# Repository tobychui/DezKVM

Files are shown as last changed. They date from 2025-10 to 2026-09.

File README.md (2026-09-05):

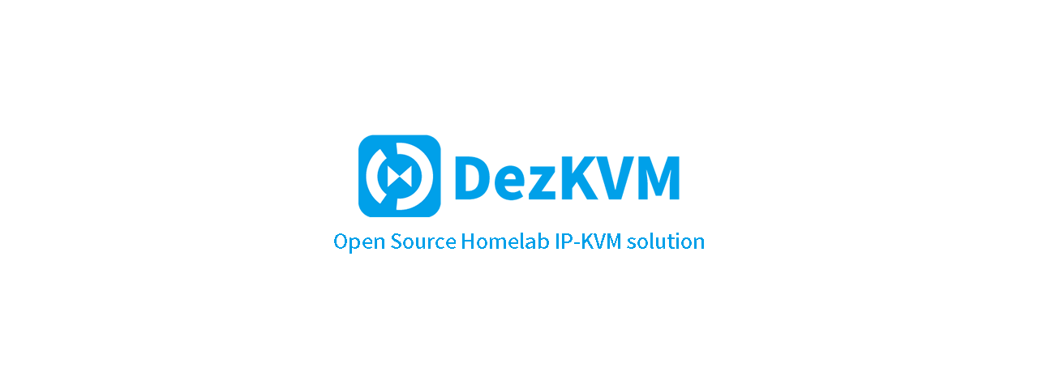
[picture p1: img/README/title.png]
title


# DezKVM — The DIY Multi-Port IP-KVM

DezKVM is an open-source, ultra-low-cost multi-port IP-KVM designed to run on standard Linux systems.

Instead of using HDMI to CSI adapter or proprietary capture hardware, DezKVM uses fully USB-based components supported by upstream Linux drivers (V4L2 and ALSA). This means the system runs on common embedded platforms such as SBCs and mini PCs without requiring any kernel patches or vendor drivers.

The goal of DezKVM is simple:

**Make scalable IP-KVM infrastructure affordable, hackable, and easy to build using commodity hardware.**

> [!WARNING]
> This project is in its very early stage and not production ready. Use with your own risk. 

If you are looking for a KVM over USB or USB-KVM device, visit [DezKVM Go](https://github.com/tobychui/DezKVM-Go) Project.

## Why DezKVM Exists

Existing DIY solutions significantly reduce cost compare to commercial solutions, but many still rely on custom kernels, specific SBC provided IO, or tightly coupled hardware platforms. 

**DezKVM takes a different approach.** 

Instead of reinventing drivers or hardware stacks, DezKVM builds entirely on top of standard USB devices already supported by Linux:

- USB Video - handled by upstream **V4L2**
- USB Audio - handled by **ALSA**
- USB HID - physical, off-the-shelf **UART to HID ASIC**
- USB ATX - communicate to host software using **USB CDC**
- All connected using a standard USB 2.0 hub

Because of this design philosophy:

- No custom kernel patches / proprietary drivers
- Works on most Linux SBCs and mini PCs (as host)
- High compatibility on different (remote) computers
- Easy multi-port scaling

## Comparison

| Feature | DezKVM | PiKVM | JetKVM | GL.iNet KVM |
| --- | --- | --- | --- | --- |
| Open Source | ✅ Fully | ✅ Mostly | ⚠️ Partial | ❌ No |
| DIY Friendly | ✅ Yes | ✅ Mostly (v1 & v2) | ❌ No | ❌ No |
| Multi-Port Support | ✅ Scale using USB hubs | ⚠️ Expensive KVM Switch required | ❌ Single Target | ❌ Single Target |
| Multi-View Support | ✅ Yes | ⚠️ Require switching | ❌ No | ❌ No |
| Hardware Lock-in | ❌ None | ⚠️ Raspberry Pi | ✅ Vendor HW | ✅ Vendor HW |
| Uses Standard Linux Drivers | ✅ Yes | ⚠️ Partial | ❌ Custom Stack  | ❌ Proprietary |
| Custom Kernel Required | ❌ No | ⚠️ Sometimes | ✅ Yes | ✅ Yes |
| Cost per Remote | ⭐ Very Low | Medium | High | High |
| Offline Operation | ✅ Yes | ✅ Yes | ✅ Yes | ✅ Yes |
| Hackable / Extendable | ✅ High | Medium | Low | Very Low |

## Build

### Dezkvmd (DezKVM daemon)

The Dezkvmd is a golang written piece of code that runs on a x86 or ARM computer with Debian based Linux installed. Require v4l2 and alsa with kernel 6.1 or above.  

To build the dezkvmd, you will need go compiler. The go package manager will take care of the dependencies during your first build. 

```bash
cd dezkvmd/
go mod tidy
go build

sudo ./dezkvmd
# or use ./dezkvmd -h to show all start options
```
### Setup Systemd Service

Create a systemd service file at `/etc/systemd/system/dezkvmd.service`:

```ini
[Unit]
Description=dezKVM IP-KVM Daemon
After=network-online.target
Wants=network-online.target

[Service]
Type=simple
User=root
WorkingDirectory=/path/to/DezKVM/src/dezkvmd
ExecStart=/path/to/DezKVM/src/dezkvmd/dezkvmd -mode=ipkvm
Restart=always
RestartSec=5

[Install]
WantedBy=multi-user.target
```

Replace `/path/to/dezKVM` with the actual path to your dezKVM installation directory.

Then enable and start the service:

```bash
sudo systemctl daemon-reload
sudo systemctl enable dezkvmd
sudo systemctl start dezkvmd
```

Check the service status:

```bash
sudo systemctl status dezkvmd
```

#### Install Dependencies

Some packages are required to run DezKVM (Require Linux kernel 6.1 or above, Debian based distro recommended). If your `go build` command above failed due to missing v4l2 types or user space properties, you can install the dependencies by running the following command. 

```
sudo apt install build-essential libv4l-dev v4l-utils 
```

If your system fail to capture audio output from remote device, or show invalid audio device properties, install the missing alsa utilities with the following command. 

```
sudo apt install alsa-utils
```

Disk formatting also requires some of the packages to provide support for file system types like exFAT or NTFS if they are not already avaible on your system. 

```
sudo apt install exfatprogs ntfs-3g
```

### Hardware

#### Build your own hardware

See `hardware/README.md`

## Usage

### Video Capture Configs

By default, MS2109 HDMI capture card support the following resolutions. If you are connecting to your DezKVM via the internet (not recommended), pick a resolution and fps combination that best fit your network **upload** bandwidth. If you are using your DezKVM within your internal management network, you can just pick the FHD 25 / 30fps option since local area network are at least 100mbps at the time of writing.

```
// FHD
1920 x 1080 30fps = 50Mbps
1920 x 1080 25fps = 40Mbps
1920 x 1080 20fps = 30Mbps
1920 x 1080 10fps = 15Mbps

// HD
1360 x 768 60fps = 28Mbps
1360 x 768 30fps = 25Mbps
1360 x 768 25fps = 20Mbps
1360 x 768 20fps = 18Mbps
1360 x 768 10fps = 10Mbps
```

### USBKVM-App

The USBKVM-App is a debug tool for the USB-KVM section of the DezKVM build that also serve as a USB-KVM viewer. It is used for checking if the USB-KVM subsystem works before integrating into a larger IP-KVM system. See `tools/usbkvm-app/` for more information.

## Screenshots

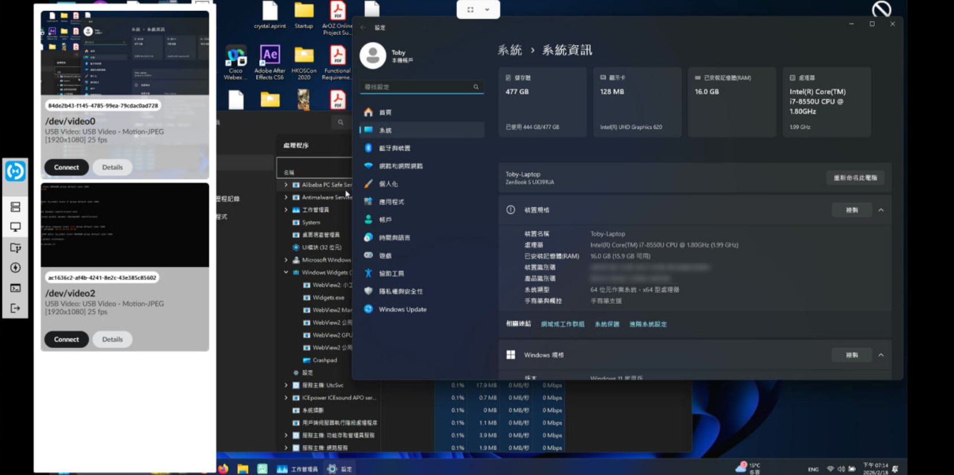
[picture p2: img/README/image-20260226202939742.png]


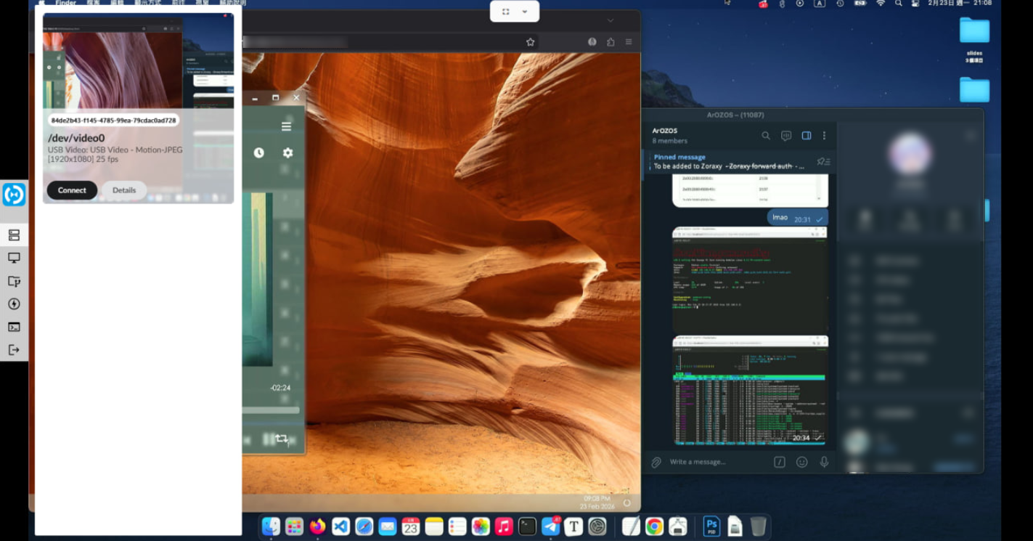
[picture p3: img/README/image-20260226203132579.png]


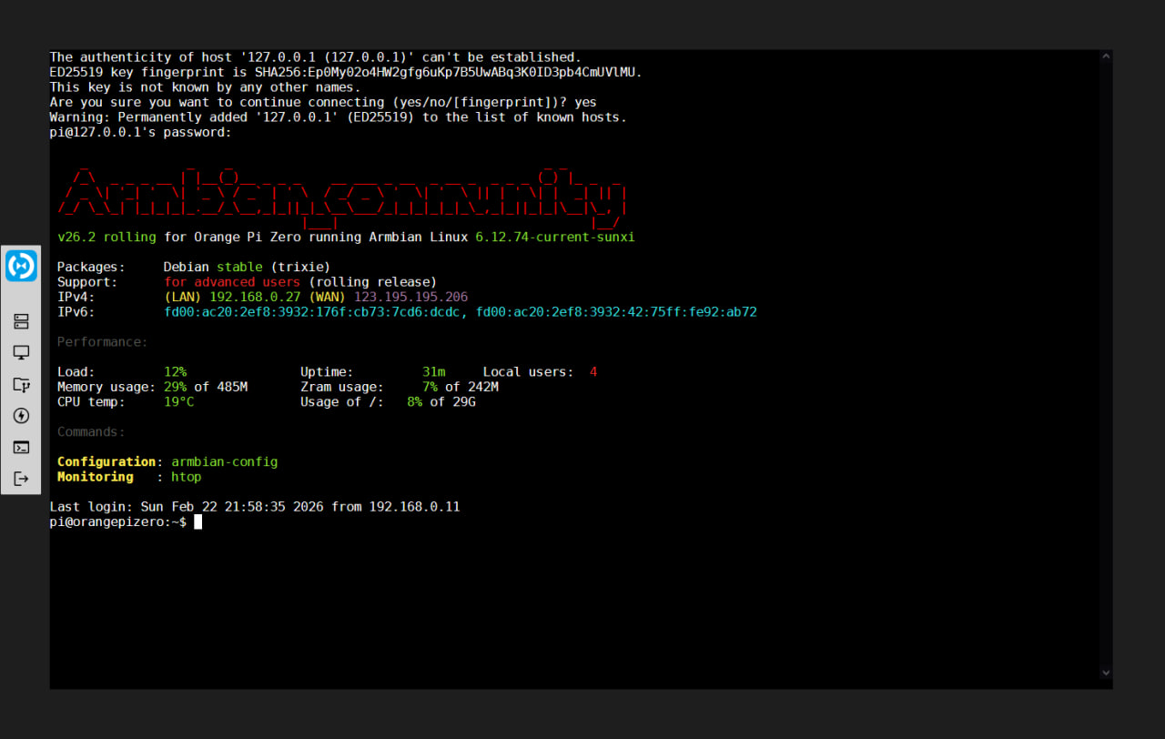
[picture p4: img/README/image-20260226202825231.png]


## License

DezKVM
Copyright (C) 2025 Toby Chui

DezKVM is free software; You can redistribute it and/or modify it under the terms of:
  - the GNU Affero General Public License version 3 as published by the Free Software Foundation.
You don't have to do anything special to accept the license and you don’t have to notify anyone which that you have made that decision.

DezKVM is distributed in the hope that it will be useful, but WITHOUT ANY WARRANTY;
without even the implied warranty of MERCHANTABILITY or FITNESS FOR A PARTICULAR PURPOSE.
See your chosen license for more details.

You should have received a copy of both licenses along with DezKVM.
If not, see <http://www.gnu.org/licenses/>.

**Note: There will be no support if you are using 3rd party parts or systems. If you are creating a new issue, make sure you are using the official implementation here with the recommended hardware and software setups**

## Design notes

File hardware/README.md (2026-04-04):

# Hardware Guide

This guide walks you through building, flashing, and cabling the DezKVM IP-KVM system from scratch. It is written with first-time hardware builders in mind — do not skip sections, as each step builds on the previous one.

---

## Table of Contents

1. [System Overview](#system-overview)
2. [Components](#components)
3. [Building the DezKVM PoC USB-KVM Module](#building-the-dezkvm-poc-usb-kvm-module)
4. [Flashing the Onboard CH552G MCU](#flashing-the-onboard-ch552g-mcu)
5. [Configuring the CH9329 Baud Rate](#configuring-the-ch9329-baud-rate)
6. [Connecting to a Host SBC (Multiple KVM Ports, No HDMI Switch)](#connecting-to-a-host-sbc-multiple-kvm-ports-no-hdmi-switch)
7. [Building and Connecting the ATX Board](#building-and-connecting-the-atx-board)
8. [Optional: OLED HMI Display](#optional-oled-hmi-display)
9. [Troubleshooting](#troubleshooting)

---

## System Overview

DezKVM is a fully **USB-protocol-based** IP-KVM system. Unlike PiKVM and similar projects, it does not require a dedicated HDMI switch, HDMI-to-CSI adapter, custom kernel drivers, or an FPGA. Everything on the DezKVM port module enumerates as standard USB devices — the host SBC sees a USB hub containing a video capture device, a USB-to-UART adapter, and a serial ACM device. This means the Linux kernel requires no patches or custom modules.

A complete system looks like this:

```
[ Host SBC (Orange Pi / Raspberry Pi / etc.) ]
         |
    USB 2.0 cable (one per KVM port)
         |
[ DezKVM Port Module ] ── HDMI ──► [ Remote Computer being controlled ]
         |                ─── USB-C (HID) ──────────────────────────►
         |                ─── RJ45 ATX cable ──► [ ATX Board ]
         |                                               |
         |                                   Dupont wires to front-panel header
```

You can connect **multiple DezKVM Port Modules** to a single host SBC — one per computer you want to control. The `dezkvmd` daemon on the SBC identifies each module by its unique UUID and routes keyboard/mouse/video to the correct session. There is no need for any external HDMI matrix switch or KVM switch box.

---

## Components

Before you start building, gather everything listed below.

### Per DezKVM Port Module

| Item | Notes |
|---|---|
| DezKVM PoC PCB (v8 recommended) | Order from your PCB fab using the Gerber files in `DezKVM PoC/pcb/v8/` |
| MS2109 HDMI capture card module | A small plug-in module; search for "MS2109 HDMI capture card" — they are very inexpensive |
| All SMD components per BOM | BOM CSV is provided in `DezKVM PoC/pcb/v8/` |
| 3D-printed enclosure | STL files in `DezKVM PoC/3d_models/` (front, back panels + HDMI capture holder) |

### For ATX Power Control (optional, one per controlled computer)

| Item | Notes |
|---|---|
| ATX Board PCB | Gerber files in `ATX board/PCB/` |
| RJ45 connector (18.3 mm pitch) | Connects the ATX board to the Port Module |
| 4× 2×2p 2.54 mm male pin headers | Front-panel connector blocks |
| 5× M3×5 mm screws | For mounting |
| Dupont wires | 8× Male-to-Female (front-panel to ATX board) + 8× Female-to-Female (ATX board to motherboard header) |
| 3D-printed parts | `ATX board/3d_models/` — PCIe bracket, mount, and optional cable press |

### Host SBC

Any Linux-capable single-board computer with USB 2.0 ports works. More USB ports means more KVM ports you can run simultaneously:

| SBC | Ethernet | USB Ports | Recommended Port Modules | Max Concurrent Sessions |
|-----|---|---|---|---|
| Orange Pi Zero LTS | 100 Mbps | 3 | 1–2 | 1 |
| Orange Pi Zero 2 | 1 Gbps | 3 | 2–4 | 4 |
| NanoPi Zero 2 | 1 Gbps | 1 | 1–4 | 4 |
| Raspberry Pi 4 | 1 Gbps | 4 | 4 | 4 |

> You can always add more Port Modules. The limits above are practical bandwidth guidelines — each module uses ~80–90 Mbps at 1080p 25 fps MJPEG.

---

## Building the DezKVM PoC USB-KVM Module

### Step 1 — Order the PCB

Open `DezKVM PoC/pcb/v8/` and upload the Gerber zip file to a PCB fabrication service (JLCPCB, PCBWay, etc.). Standard 2-layer, 1.6 mm FR4 settings work fine. If the fab offers SMT assembly, the BOM CSV and Pick & Place CSV are also provided in that folder for JLCPCB assembly service.

### Step 2 — Solder the components

If you are assembling by hand, use the schematic PDF in `DezKVM PoC/pcb/v8/` as your reference. Key chips and their placement:

| Chip | Role | Notes |
|---|---|---|
| SL2.1A | USB 2.0 hub | Groups all downstream devices under one USB tree |
| CH552G | Onboard MCU | Handles ATX control, USB mass-storage switching, UUID service, HDMI power control |
| CH340C | USB-to-UART bridge | Bridges the SBC's USB to the CH9329 |
| CH9329 | UART-to-USB-HID | Emulates keyboard and mouse on the remote side — no driver needed on the controlled PC |
| CH440G | USB signal switch | Routes the internal USB Type-C port between SBC and remote |
| MS2109 module | HDMI capture | Plug-in module; press it into the slot on the PCB |

> **First-time soldering tip:** Start with the smallest SMD components first (resistors and capacitors), then the ICs, and finish with connectors. For the QFN/SOP packages, use plenty of flux and a fine-tipped iron. Review the PCB silkscreen for all component orientations before powering on.

### Step 3 — Print and assemble the enclosure

Print the STL files from `DezKVM PoC/3d_models/`. The assembly consists of:
- **front.ipt / front.stl** — front plate with HDMI and USB-C cutouts
- **back.ipt / back.stl** — back plate with host-side USB-C and PROG header access
- **capture_holder_top / capture_holder_bottom** — holds the MS2109 module in the correct position

PLA at 0.2 mm layer height works well. Orient the flat face of each part down when printing to avoid supports.

### Step 4 — Ports at a glance

Once assembled, you will see:

**Remote side (faces the computer you are controlling):**
- HDMI input — connect to the remote computer's HDMI output
- RJ45 ATX control port — connect to the ATX board (optional)
- USB-C (upper) — USB mass-storage passthrough
- USB-C (lower, closer to HDMI) — USB HID (keyboard + mouse to remote PC)

**Host side (faces your SBC):**
- USB-C (USB 2.0) — single cable to your SBC; everything goes through this
- XH2.54 1×4p white header — alternative connection if you prefer a JST header over USB-C
- PROG header (unpopulated by default) — only needed for certain reprogramming scenarios

---

## Flashing the Onboard CH552G MCU

The CH552G is an 8051-based microcontroller that runs the ATX control, UUID service, and HDMI power management firmware. It is programmed using the Arduino IDE with the **ch55xduino** board support package.

### Prerequisites

1. Download and install [Arduino IDE](https://www.arduino.cc/en/software) (version 2.x recommended).
2. In Arduino IDE, go to **File → Preferences** and add this URL to the "Additional boards manager URLs" field:
   ```
   https://raw.githubusercontent.com/DeqingSun/ch55xduino/unreal/package_ch55xduino_mcs51_index.json
   ```
3. Open **Tools → Board → Boards Manager**, search for `CH55x`, and install the ch55xduino package.
4. Open the firmware sketch that matches your PCB version from `DezKVM PoC/firmware/`. For v7 or v8 PCBs, use `For v7 PCB/usbkvm_fw/usbkvm_fw.ino`.

### First-Time Flash (bootloader mode entry)

The CH552G ships without firmware. To enter its USB bootloader, you must hold down the FLASH button on the PCB **before** the chip sees USB power. Follow these steps exactly in order:

1. Open the firmware sketch in Arduino IDE and click **Compile** (the tick/check button). Wait for it to finish — this caches the binary and makes the next step faster.
2. Set the upload settings under **Tools**:
   - **Clock**: `24MHz (Internal)`
   - **Upload method**: `USB CODE w/ 148B USB RAM`
3. **Hold down the FLASH button** on the PCB. Do not release it yet.
4. While still holding FLASH, plug the **host-side USB-C cable** from the PCB into your PC.
5. Check your device manager (Windows) or `lsusb` (Linux). You should see:
   - A USB hub (SL2.1A)
   - A USB video/audio device (MS2109 capture card, if installed)
   - A USB-to-UART adapter (CH340C)
   - An **Unknown Device** — this is the CH552G in bootloader mode
6. In Arduino IDE, click **Upload** (the right-arrow button). You do not need to select a serial port for the first flash.
7. Watch the IDE output. **The moment you see the compilation phase finish and the upload phase start, release the FLASH button.** This is the critical timing window:
   - Release too late → upload times out
   - Release too early → CH552G resets out of bootloader before the upload completes
   - If it fails, unplug the cable and repeat from step 3
8. When successful, the Unknown Device disappears from your device manager and a new **COM port / ttyACM device** appears. This is the CH552G running its firmware.

> The first flash is the hardest part of building this device. It may take 2–3 attempts to get the button timing right. This is normal — do not be discouraged.

### Subsequent Firmware Updates

After the first flash is done, the ch55xduino bootloader is triggered automatically via the serial port. Future updates work exactly like any Arduino board:

1. Select the correct COM port / ttyACM device under **Tools → Port**.
2. Click **Upload**.

No button holding is required.

---

## Configuring the CH9329 Baud Rate

The CH9329 (keyboard/mouse emulator chip) ships with a default baud rate of **9600 bps**, which is too slow for smooth KVM control. You need to change it to **115200 bps** once after first assembly.

> This step requires the `dezkvmd` software to be built. See the main `src/dezkvmd/` directory for build instructions.

1. Plug the **host-side USB-C** port into your SBC (or any Linux PC).
2. Take a separate USB power source (a phone charger is fine) and plug it into the **lower USB-C port** on the remote side of the KVM module — the one closer to the HDMI connector. This powers up the CH9329 independently so the configuration can reach it.
3. On the SBC / Linux machine, run:
   ```bash
   src/dezkvmd/configure_chip.sh
   ```
   If the CH340C UART adapter enumerated on a different path than `/dev/ttyUSB0`, edit `src/dezkvmd/config/usbkvm.json` to match before running the script.
4. Wait for the script to complete without errors.
5. Unplug the power from the lower USB-C port.
6. Connect the **remote computer's USB port** to that lower USB-C port — keyboard and mouse should now feel immediate and responsive.

---

## Connecting to a Host SBC (Multiple KVM Ports, No HDMI Switch)

This is the feature that sets DezKVM apart: **you do not need a dedicated HDMI switch** (like the PiKVM HDMI switch) because each port module is an independent USB device. Adding another KVM port just means plugging in another USB cable.

### How it works

Each DezKVM Port Module contains a **SL2.1A USB 2.0 hub** that groups all of its downstream USB devices under a single USB tree. When plugged into the SBC, the Linux kernel sees:

| Linux Device | What it is |
|---|---|
| USB hub (SL2.1A) | The "identity container" of one KVM port |
| `/dev/video*` + ALSA sound card | MS2109 HDMI capture — video and audio from the remote machine |
| `/dev/ttyUSB*` (ch341 driver) | CH340C UART bridge — the pipe that carries keyboard/mouse commands to CH9329 |
| `/dev/ttyACM*` (CDC ACM) | CH552G MCU — ATX control, USB mass-storage switching, UUID queries |

The `dezkvmd` daemon queries `u` (UUID command) on each `ttyACM` device at startup to build a map of **UUID → USB tree → video device + ttyUSB + ttyACM**. This is how it knows which keyboard/mouse pipe belongs to which video stream, even after rebooting or re-plugging modules.

### Single-port setup

```
[ SBC USB port 1 ]
      |
[ DezKVM Port Module 1 ]
      |── HDMI ──► Computer A
```

Connect the host-side USB-C of the Port Module to any USB 2.0 or USB 3.0 port on the SBC. USB 3.0 ports are backwards compatible with USB 2.0.

### Multi-port setup

```
[ SBC USB port 1 ] ──► [ DezKVM Port Module 1 ] ──► Computer A
[ SBC USB port 2 ] ──► [ DezKVM Port Module 2 ] ──► Computer B
[ SBC USB port 3 ] ──► [ DezKVM Port Module 3 ] ──► Computer C
```

Each module plugs directly into its own USB port on the SBC. If your SBC has fewer physical USB ports than you need, you can use a **USB 2.0 hub** to expand — just be aware that all modules behind the same hub share the bandwidth of that hub's upstream port.

```
[ SBC USB port 1 ] ──► [ USB 2.0 Hub ]
                               |──► [ DezKVM Port Module 1 ] ──► Computer A
                               |──► [ DezKVM Port Module 2 ] ──► Computer B
```

> **Bandwidth note:** Each module uses ~80–90 Mbps at 1080p 25 fps. USB 2.0 practical throughput is around 400 Mbps, so two modules per hub port is comfortable; four is the realistic maximum when all sessions are active simultaneously.

### Why no HDMI switch is needed

With PiKVM and similar designs, the SBC has only one HDMI input (via CSI adapter), forcing you to use an external HDMI matrix switch to route signals. DezKVM avoids this completely because:

- Each Port Module has its **own dedicated HDMI capture chip** (MS2109).
- Each capture chip is an independent USB UVC device on the SBC.
- The SBC sees as many independent video streams as there are Port Modules plugged in.

Each stream can be viewed, recorded, or controlled independently and simultaneously — no switching required.

---

## Building and Connecting the ATX Board

The ATX board gives the SBC the ability to press the power button, press the reset button, and read the power LED and hard-drive LED of the controlled computer — exactly like physically sitting in front of it.

### Build the ATX Board PCB

Order the PCB using the Gerber files in `ATX board/PCB/` and populate it using the parts list in `ATX board/README.md`. The board is simple: it contains just a few jumper controlled by four **EL817 optocouplers in the KVM port unit**, providing electrical isolation between the KVM and the controlled PC's front-panel header. There is no MCU on the ATX board itself — all logic runs on the CH552G inside the Port Module.

3D-print the parts from `ATX board/3d_models/`:

- **pcie-bracket.stl** — mounts into any empty PCIe slot bracket hole on the back of the PC case, giving you a clean exterior mounting point
- **atx-adapter_mount.stl** — holds the ATX PCB in place
- **atx-adapter_cable-press.stl** — optional cable management clip instead of zip ties

### Wire the ATX Board to the Motherboard

The motherboard's front-panel header is usually a 2×5 or 2×9 pin block near the bottom-right of the board, labelled something like `F_PANEL` or `JFP1`. Consult your motherboard manual for the exact pinout. Using **Female-to-Female Dupont wires**, connect:

| ATX Board header | Motherboard front-panel pin |
|---|---|
| PWR_SW + | Power switch signal |
| PWR_SW − | Power switch ground |
| RST_SW + | Reset switch signal |
| RST_SW − | Reset switch ground |
| PWR_LED + | Power LED anode |
| PWR_LED − | Power LED cathode |
| HDD_LED + | HDD LED anode |
| HDD_LED − | HDD LED cathode |

The ATX board's four 2×2p headers are labelled on the PCB silkscreen. If your case already has front-panel wires plugged into the motherboard, use **Male-to-Female Dupont wires** to daisy-chain from the existing wires to the ATX board, then from the ATX board to the motherboard header.

### Connect the ATX Board to the Port Module

Run an **RJ45 Ethernet cable** (standard Cat5e or Cat6 patch cable) between:
- The RJ45 port on the ATX board
- The **RJ45 ATX control port** on the remote side of the DezKVM Port Module

The cable carries the four isolated signals (power switch, reset switch, power LED, HDD LED) between the ATX board and the CH552G on the Port Module. No special pinout or crossover cable is required — a straight-through patch cable is correct.

> **Safety note:** The EL817 optocouplers on the ATX board electrically isolate the KVM circuitry from the motherboard's front-panel signals. Do not bypass or remove them.

---

## Optional: OLED HMI Display

The OLED HMI PCB (`OLED_hmi_pcb/`) is an optional status display that connects to the SBC via USB UART. It uses the same CH552G MCU and a 0.96-inch SSD1306 OLED. Firmware and PCB files are in `OLED_hmi_pcb/`. The `dezkvmd` daemon communicates with it using a length-type-value UART protocol to render text and respond to the two capacitive touch buttons on the board.

This is a cosmetic and convenience addition — the KVM system is fully functional without it.

---

## Troubleshooting

| Symptom | Likely cause | Fix |
|---|---|-----|
| Arduino IDE upload times out during first flash | Released FLASH button too late | Unplug USB, hold FLASH again, replug, and release button faster after upload starts |
| CH552G keeps resetting during first flash | Released FLASH button too early | Unplug USB, hold FLASH again, replug, keep holding until IDE shows "uploading" |
| No video device appears on SBC | MS2109 module not seated properly, or HDMI source not active | Re-seat the capture module; verify the remote PC has a display output on that HDMI port |
| Keyboard/mouse is sluggish or drops inputs | CH9329 still running at 9600 bps | Re-run `configure_chip.sh` as described in the CH9329 section above |
| `dezkvmd` cannot find a module | Module is on a different ttyACM/ttyUSB path | Edit `config/usbkvm.json` to point to the correct device paths |
| ATX power/reset commands have no effect | RJ45 cable not connected, or wrong motherboard header wiring | Check the patch cable and verify Dupont wire connections against the motherboard manual |
| Two modules have the same UUID | UUID was regenerated accidentally | Send command `u` to each ttyACM device individually to read UUIDs; use `z` (debug) to regenerate one if duplicated |

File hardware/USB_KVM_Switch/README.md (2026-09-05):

# Software Controlled USB KVM Switch

A DIY USB KVM (Keyboard, Video, Mouse) switch designed for homelab environments. This project includes firmware, a cross-platform control application, PCB design, and 3D models for the enclosure. 

It works with DezKVM (or any kind of IP-KVM as soon as both hosts, PC1 and PC2 that you are remote connecting got a desktop interface or serial interface driver that support USB ACM serial devices) for switching USB (and additional connections, see State Synchronize MOSFET section below) between two hosts.

## Overview

This is a complete hardware and software solution for switching USB keyboard, video, and mouse between multiple computers using a simple USB device with a companion control application.

## Photos

Here are some photos of the USB KVM Switch device (large one) together with my previous DIY 7 ports USB hub (small one)

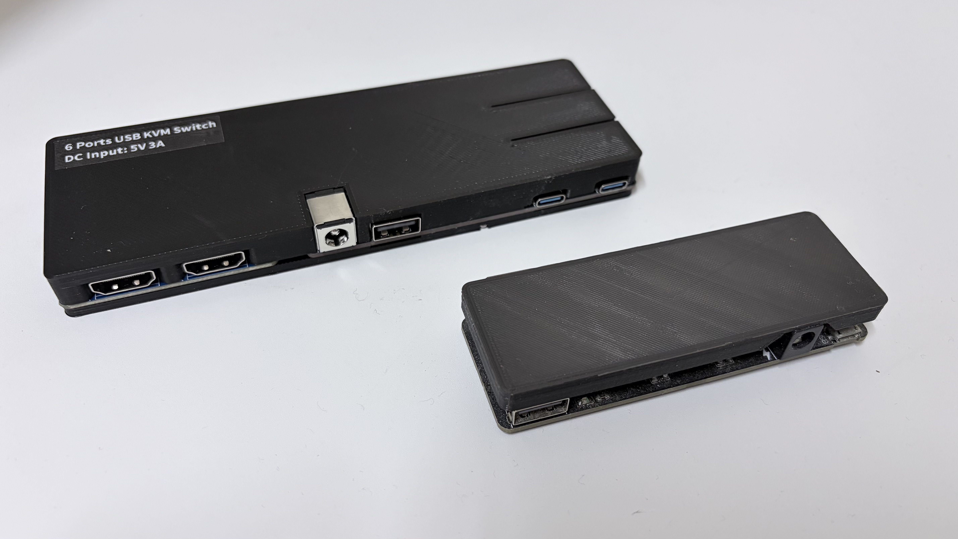
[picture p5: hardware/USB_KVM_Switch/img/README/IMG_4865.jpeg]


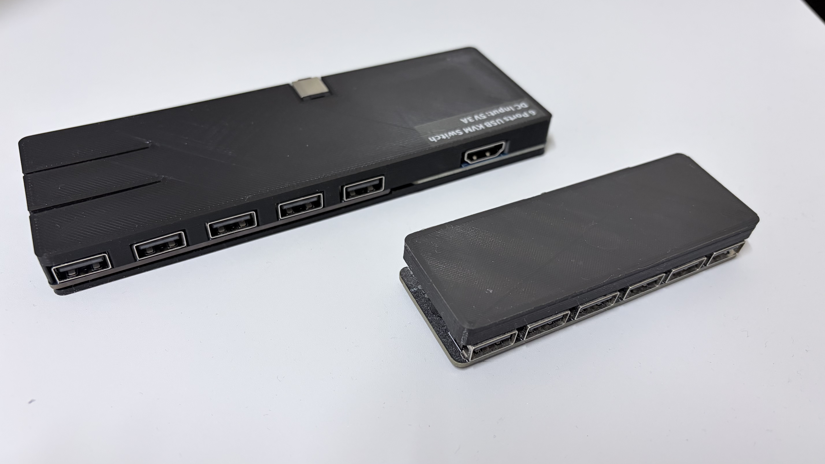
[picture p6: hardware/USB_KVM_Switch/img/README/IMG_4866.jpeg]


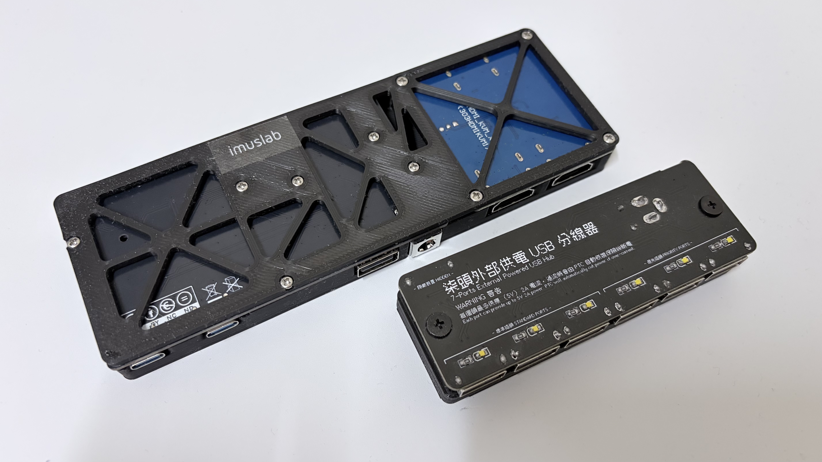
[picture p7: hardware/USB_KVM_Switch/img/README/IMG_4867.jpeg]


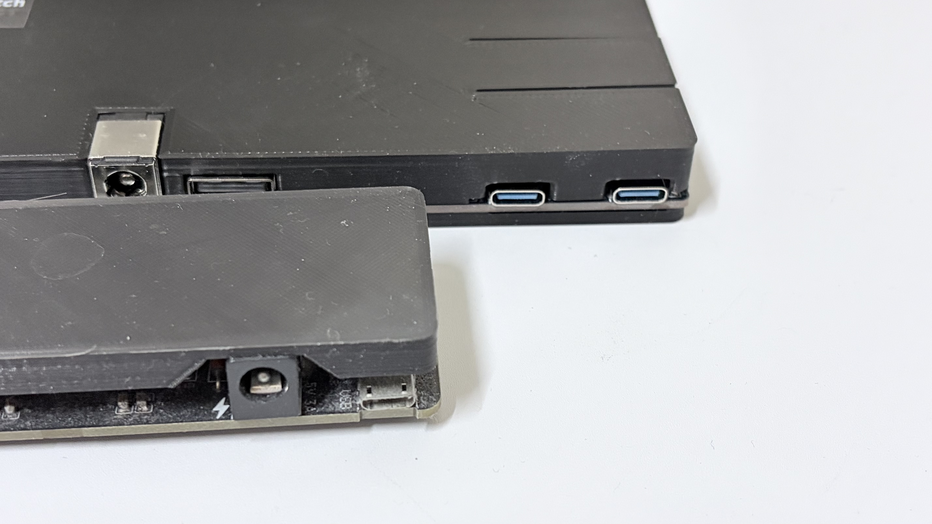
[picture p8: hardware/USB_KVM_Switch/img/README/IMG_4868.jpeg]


## Synchronize Switching with Other Connectors/ Devices

### State Synchronize MOSFET 

There is an onboard MOSFET that pull up / down with the host switch status. You can use that electrical signal to control other devices or modules. For example, this is an off-the-shelf HDMI switch module that has been modified to use with the USB KVM switch. The original 2 way toggle switch has been replaced by a 1k Ohm resistor (to keep the signal pin pull high) and the pull ground behavior is triggered by the onboard N channel MOSFET (AO3400)



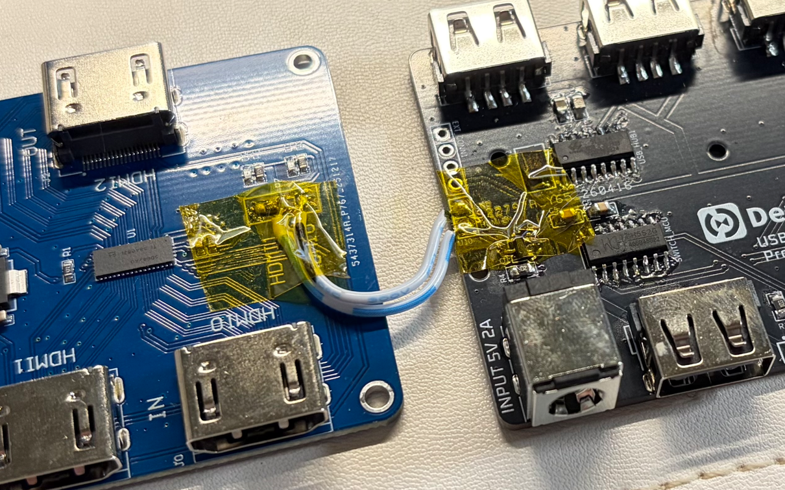
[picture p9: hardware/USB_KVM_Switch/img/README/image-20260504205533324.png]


### Slave Device IO

There are an additional 4 2.54*4 pins at the edge of the board for linking another devices with MCU if needed. So switch states can be synchronized between two KVM switches.

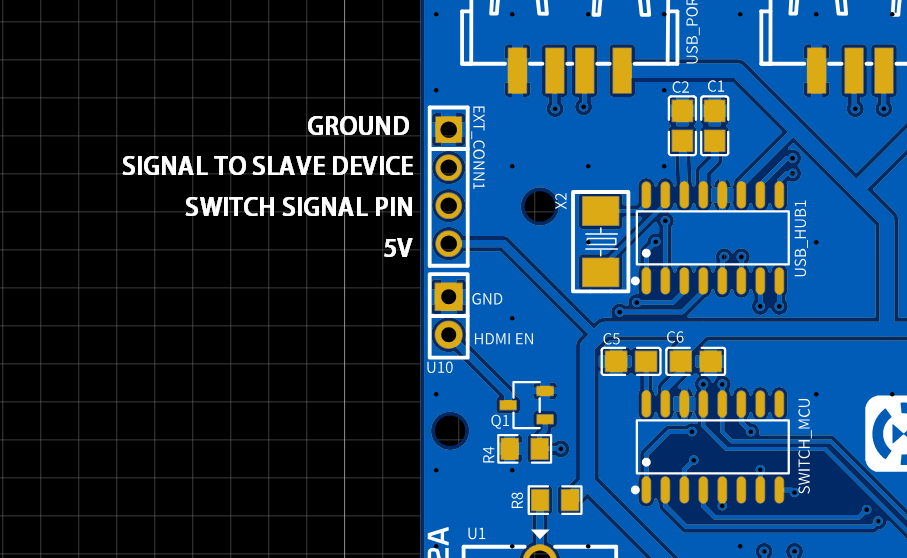
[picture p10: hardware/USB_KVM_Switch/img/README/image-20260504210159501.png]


The IO definitions are as followings.

- Electrical Ground
- Signal to slave devices, depending on the firmware, set to HIGH or LOW when the current KVM is set to HOST1 / HOST2
- Switch signal pins, electrically connected to the switch button on the right side of the board, active high (default pull low)
- 5V from DC jack or USB type C, depending on if R8 is populated

## Directory Structure

```
├── apps/                 # Go-based control application
│   ├── main.go
│   ├── port_darwin.go    # macOS serial port support
│   ├── ports_linux.go    # Linux serial port support
│   ├── ports_windows.go  # Windows serial port support
│   ├── settings.json     # Application settings
│   ├── build_*.sh/*.bat  # Build scripts for different platforms
│   └── internal/
│       ├── kvmswitch/    # Core KVM switch logic
│       └── icon/         # Systray icon resources
├── firmware/             # Arduino firmware
│   └── kvm_switch/
│       ├── kvm_switch.ino      # Main firmware
│       └── uuid_service.ino    # UUID management
├── hardware/             # PCB design and manufacturing files
│   ├── rev1/             # Revision 1 (initial release)
│   └── rev2/             # Revision 2 (current)
├── 3D models/            # Enclosure design
└── docs/
```

## Features

- **Cross-Platform**: Runs on Windows and macOS
- **Systray Integration**: Minimize to system tray for easy access
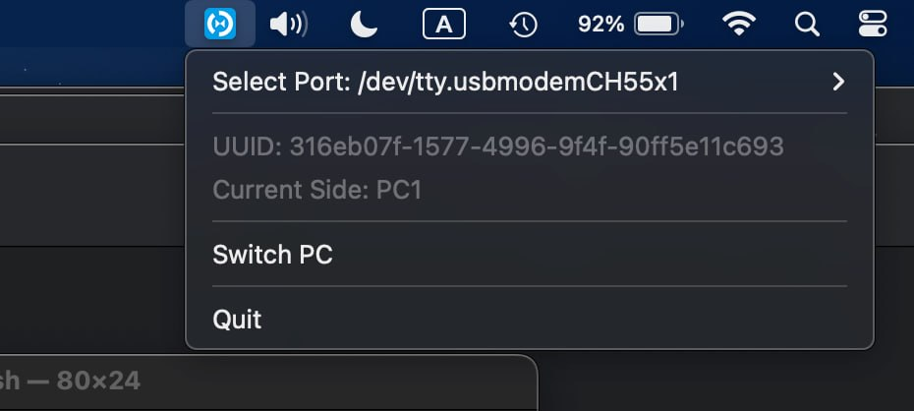
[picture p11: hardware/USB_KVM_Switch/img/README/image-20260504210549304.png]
  
- **Auto-Detection**: Automatically detects connected USB KVM switches
- **Settings Persistence**: Remembers last connected port
- **Serial Communication**: Direct control via USB serial interface

## Building

### Desktop App

#### Prerequisites

- Go 1.25.0 or later

#### Build Commands

```bash
cd ./apps
go mod tidy
go build //development build only
```

For production build (no cmd popup windows)

- **macOS**: `bash apps/build_mac.sh`
- **Windows**: `apps/build_win.bat`

### Firmware

The Arduino firmware is located in `firmware/kvm_switch/kvm_switch.ino` and can be uploaded using the Arduino IDE with CH55xduino board definitions.

### Hardware

PCB files and manufacturing data are in `hardware/` directory:
- **BOM**: Bill of Materials (CSV)
- **PCB**: PCB layout files (JSON)
- **Schematic**: Circuit schematic (JSON)
- **Pick & Place**: Component placement data (CSV)

### 3D Models

Enclosure models are designed using Autodesk Inventor:
- `cover.ipt` - Top cover
- `bottom.ipt` - Bottom enclosure
- `*_no-hdmi.*` - Variants without HDMI switch, just the USB KVM part

## Controlling with Serial

You can also optionally control it directly with serial applications like putty or Arduino IDE Serial Monitor. The commands are as follows (single character ascii at 115200 baud rate).

```
0 - Switch KVM to Host 1
1 - Switch KVM to Host 2
? - Return the current KVM switch side
u - Return the UUID in DezKVM LTV data structure
```

## IMPORTANT NOTES

**When you switch the KVM from Host 1 to Host 2, the control MCU get switched as well.**

**So if you are switching from Host 1 to Host 2 but Host 2 doesn't connects to anything, you will need to manually press the switch button to switch it back to Host 1.**

**That means you need to make sure both hosts are online before switching OR you are physically present in front of the switch / computer for switching. DO NOT USE THIS IN FULL REMOTE IP-KVM USE CASE WHEN YOU HAVE NO EASY PHYSICAL ACCESS TO THE SWITCH** 

## License

Software: AGPL

Hardware: CC BY-NC-ND

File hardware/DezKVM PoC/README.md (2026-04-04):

# DezKVM PoC (Prototype Versions)

The prototype version creates only the USB-KVM part of the whole IP-KVM.

The finalized prototype version stops at v8, with completed USB host / remote swap, KVM, HDMI capture and on board AUX MCU for handling status checking and ATX controls.

There are 4 ports exposed on the remote side

- HDMI input port
- RJ45 ATX control port
- Two USB type-C port
  - Upper one: USB mass storage switch over (the internal USB port)
  - Lower one: USB HID (keyboard and mouse emulation)

On the host side, there are two ports

- USB type C (USB 2.0)
  - Also expose as XH2.54 1*4p (USB 2.0 pins, the white connector)
- USB 2.0 PROG pins (unpopulataed in the photo below, for programming the onboard E8051 MCU)

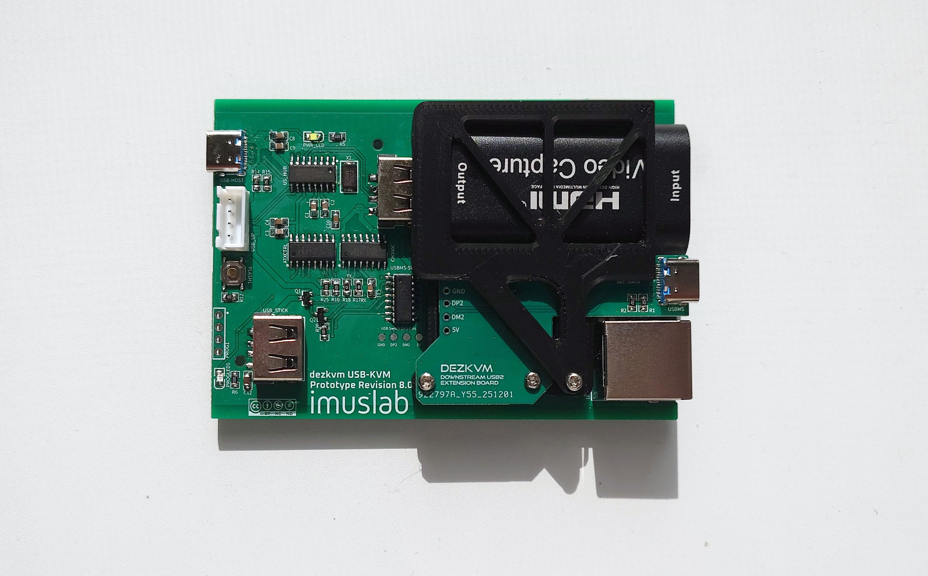
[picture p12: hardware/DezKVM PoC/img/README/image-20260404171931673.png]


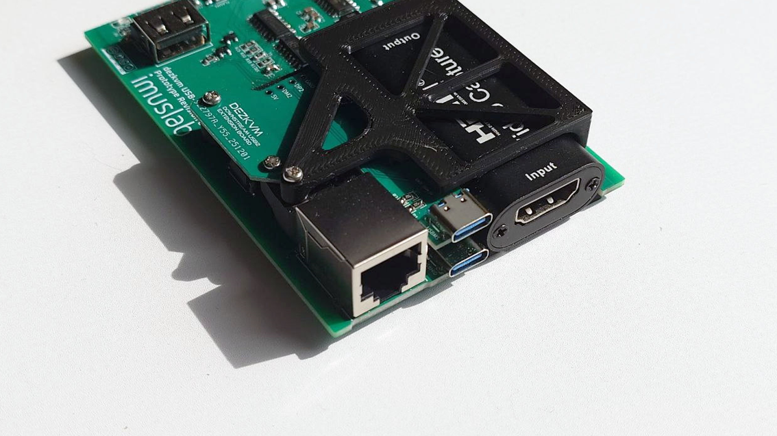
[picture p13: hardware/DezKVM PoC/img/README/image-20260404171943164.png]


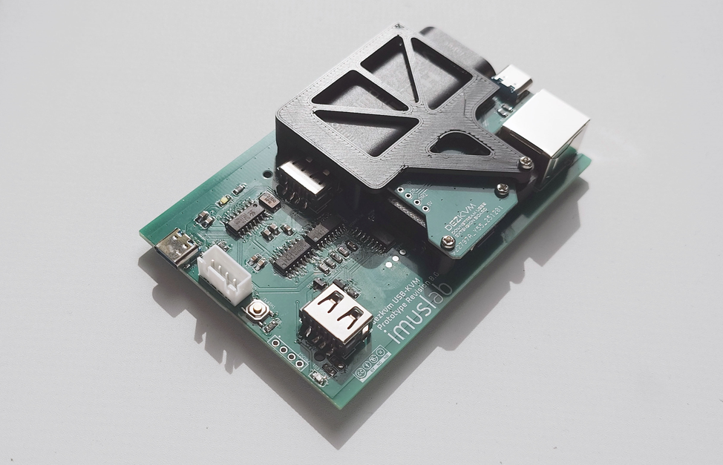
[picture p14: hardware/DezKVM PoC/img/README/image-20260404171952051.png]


## Using as a USB-KVM device

After installing the PCB into a proper case, you can also use it as a dedicated USB over KVM device. 

For the control interface and usage instructions, see [DezKVM Go](https://github.com/tobychui/DezKVM-Go)  (which is a spin-off of this project)

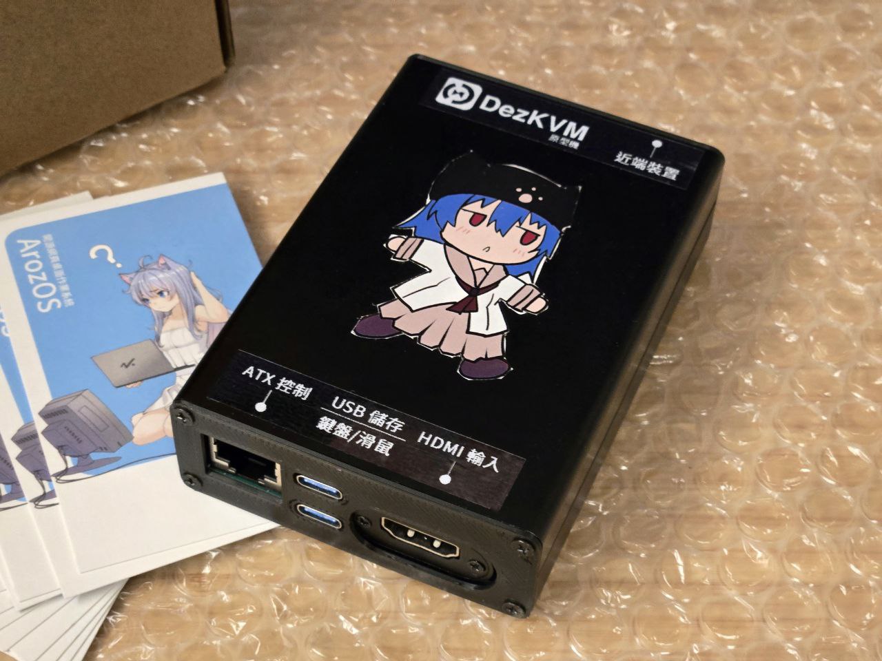
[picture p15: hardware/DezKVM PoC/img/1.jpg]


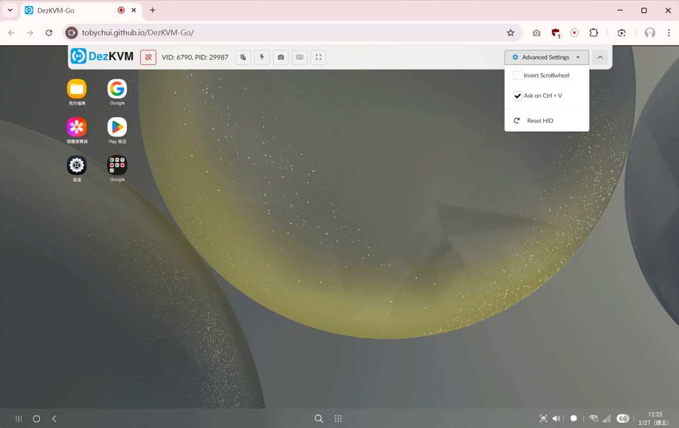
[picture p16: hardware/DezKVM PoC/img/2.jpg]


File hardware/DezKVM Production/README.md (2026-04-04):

# DezKVM Hardware

## Introduction

The DezKVM is compose of the following hardware connected together

- 1 x Host Computer (e.g. Orange Pi, Raspberry Pi, NanoPi)
- 1 x Power Management Board
- n x DezKVM Port Module
- (Optional) Display Module

### Picking the correct host computer

This is the most tricky part. Since the host computer IO limits the number of Port modules you can connects (i.e. the number of port your KVM could have), it is best to first decide how many ports you need and pick the suitable host computer.

The maximum bandwidth of each of the Port module is around 80 - 90Mbps at 1080p 25fps MJPEG mode with 48kHz PCM stereo channels. So the bottleneck would always be either the USB tree or the ethernet speed. However, depending on how you use it (for example you prefer switching between one of remotes, or connect to multiple sessions at once), configuration might varies according to your purpose. Here are some examples and recommendations.

| Single Board Computer | Ethernet Bandwidth | USB Ports | Recommended No. of Port Modules | Max Concurrent Sessions |
| --- | --- | --- | --- | --- |
| Orange Pi Zero LTS | 100Mbps | 3 | 1 - 2 | 1 |
| Orange Pi Zero 2 | 1Gbps | 3 | 2 - 4 (2 host port each with 1 hub, each hub have 2 port module) | 4 (All ports) |
| NanoPi Zero2 | 1Gbps | 1 | 1 - 4 (1 host port with 1 hub,  4 port modules as downstream) | 4 (90Mbps x 4 will max out the only USB 2.0 port real world speed) |
| Raspberry Pi 3+ | 300Mbps | 4 | 2 (USB port and ethernet chip share the same bus) | 2 (All ports) |
| Raspberry Pi 4 | 1Gbps | 4 | 4 | 4 |

Here are just examples. **You can always connects more Port modules, just make sure you have enough bandwidth when connecting to multiple sessions at the same time.** 

## DezKVM Port Module – Technical Specifications

The key feature of the DezKVM Port module is the modularity and ease of building. It use all hardware components and no emulated USB composite device, allowing highest compatibility with existing computer / OSes. 

- Fully USB protocol-based architecture
- Modular and scalable
- No FPGA required
- No custom Linux drivers
- Designed for multi-port IP-KVM chaining

### General

| Item | Specification |
| --- | --- |
| Module Type | USB-based KVM Extension Module |
| Architecture | USB Hub + Downstream USB Devices |
| Host Interface | USB 2.0 High-Speed (480Mbps) |
| Operating System Support | Linux (Upstream Drivers Only) |
| Custom Kernel Drivers Required | No |
| Expansion Method | USB Hub Chaining |

---

### USB Hub Core

| Item | Specification |
| --- | --- |
| USB Hub IC | SL2.1A |
| Upstream Ports | 1 |
| Downstream Ports | 4 |
| USB Version | USB 2.0 |
| Clock | 12 MHz Crystal |
| Power | 5V USB Bus Powered |

---

### Video Capture Subsystem

| Item | Specification |
| --- | --- |
| Capture Interface | HDMI Input |
| Capture Chip | MS2109 (USB UVC Device) |
| Linux Support | V4L2 (UVC Standard Driver) |
| Max Resolution | Up to 1080p 25fps (Module Dependent) |
| Audio Support | HDMI Embedded Audio |
| Audio Driver | ALSA (USB Audio Class) |

---

### HID Emulation

| Item | Specification |
| --- | --- |
| HID Controller | CH9329 |
| Function | USB Keyboard + Mouse Emulation |
| Control Interface  | UART |
| Status LED | TX/RX Activity Indicators |
| Driver Requirement | Native USB HID <br />(No Driver Needed on remote side) |

---

### Control Channel

| Item | Specification |
| --- | --- |
| USB-UART Bridge | CH340C |
| Purpose | SBC to HID/Control Communication |
| Linux Driver | ch341 (Upstream) |
| Baud Rate | 115200bps |

---

### USB Mass Storage Switching

| Item | Specification |
| --- | --- |
| USB Switch IC | CH440G |
| Power Control | AO3400A / AO3401A  MOSFET<br />(VCC side switching) |
| Function | Dynamically switch USB mass storage device |
| Use Case | ISO mounting / recovery tools |

---

### ATX Power Control Module

| Item | Specification |
| --- | --- |
| MCU | CH552G |
| ATX Signals | PWR_SW, RST_SW |
| LED Monitoring | PWR_LED, HDD_LED |
| Isolation | EL817 Optocouplers x 4 |
| Compatibility  | PiKVM ATX Pinout Compatible (To be tested) |

---

### Electrical

| Item | Specification |
| --- | --- |
| Input Voltage | 5V USB Powered |
| Power Filtering | Bulk + 100nF Decoupling |
| Status LEDs | Power, Activity, Programming |
| ESD Protection  | USB Port Level |

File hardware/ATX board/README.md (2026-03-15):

# DezKVM ATX board

The DezKVM ATX board has the same pin layout as PiKVM ATX board but in a more refined package.

## Parts

- ATX board PCB
- RJ45 conector (18.3mm)
- 4 x 2x2p 2.54 male header
- 3D printed parts 
- 5 x M3x5mm screws
- Dupont Wires of required lengths (depends on your PC case and motherboard layout)
  - 8 x Male to Female (Front-panel to ATX board) 
  - 8 x Female to Female (ATX board to motherboard front-panel headers)
- (Optional) atx-adapter_cable-press.stl model if zip-tie looks bad on your setup

## Photos

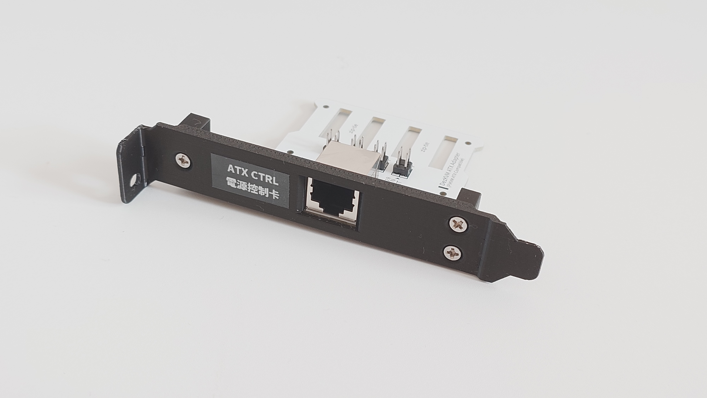
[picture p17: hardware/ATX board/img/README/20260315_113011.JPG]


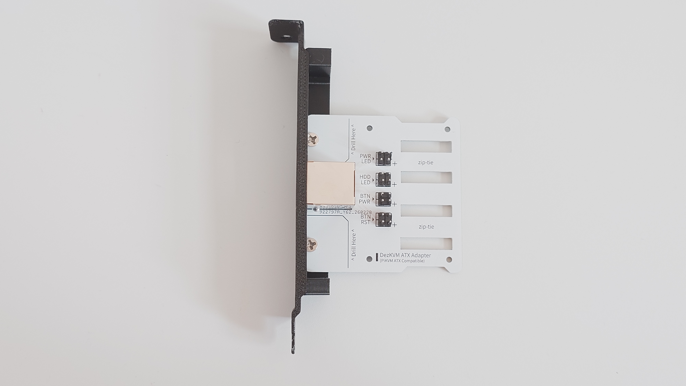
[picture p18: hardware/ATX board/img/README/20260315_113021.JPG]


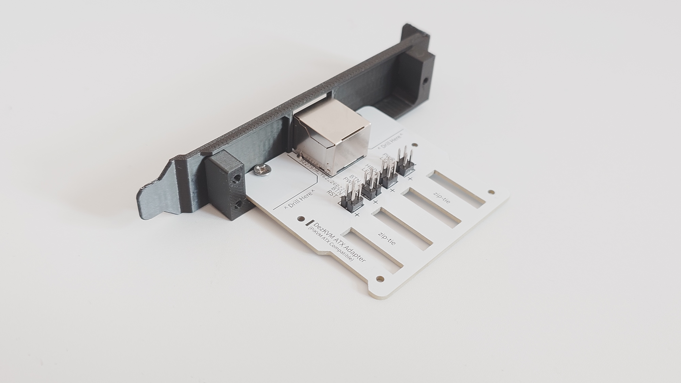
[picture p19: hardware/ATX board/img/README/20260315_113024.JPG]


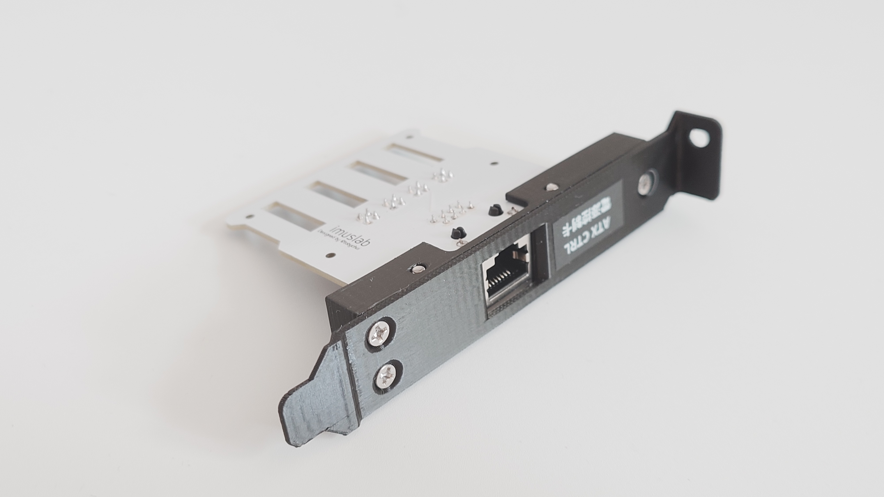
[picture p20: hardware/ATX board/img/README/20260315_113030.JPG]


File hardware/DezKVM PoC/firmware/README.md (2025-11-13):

# Firmware

## Introduction
The firmware folder contains all the firmware for different PCB versions. Pick one that matches
the PCB version you are using. 

### Onboard ICs and their purposes
There are 5 important ICs on the PCB

1. SL2.1A - A USB 2.0 hub that also act as a device tree mapper that let the host computer knows the following chips are belongs to single USB-KVM device
2. CH552G - The onboard MCU that provide a ttyACM0 device interface for toggling USB mass storage device (technically the physical port) between host and remote, as well as ATX power control and serving a UUID to identify which USB tree is a unique USB-KVM device
3. CH340 - The USB to UART converter for CH9329
4. CH9329 - The UART to USB HID bytecode converter (i.e. this chip emulate your keyboard and mouse)
5. CH440G - USB signal switch, for switching the USB port between your host computer (running dezuKVM control software) and your remote computer

For the slot on the PCB and the USB2.0 port, it is for HDMI capture card (MS2109). You can get them online for a really low price and output MJPEG stream using internal hardware encoder. See more over the dezukvmd README file.

## Flashing the CH552G onboard MCU
The usbkvm is developed with Arduino IDE. You will need the [ch55xduino broad API](https://github.com/DeqingSun/ch55xduino) installed in order to compile and flash the firmware to the USB-KVM hardware.

For first time flashing the firmware, **follow the steps below carefully**.

1. Prepare the firmware code in your Arduino
2. Press compile button and wait for the compiled binary get cached (to speed up the flash process)
3. Hold down the FLASH button on the USB-KVM PCB. **Do not release it until you are told to do so.**
4. Insert the USB cable into the USB-KVM host side port and connect it to your computer. You should see multiple device pops up in your device manager. If all parts are soldered correctly, you will see a USB hub with 3 devices under it, the USB capture card (which provide a video and audio device file), a USB to UART adapter and an unknown device. That Unknown device is our CH552g (without firmware)
5. Press the upload button in your Arduino IDE with no serial port selected
6. **Just after the code compiled, immediately release the FLASH button** (Notes: if you do this too slow, you will get a timeout in your Arduino IDE console. If you release too early, the MCU will reset itself and back to runtime mode. Try a few time if you keep having issues with this step)
7.  After the firmware upload, you should see a Serial device pop up in your device manager and the unknown device is gone. 

For future firmware re-flash or update, simply upload using the serial port like an ordinary Arduino dev board. 

## CH9329 Baudrate Change
The CH9329 defaults to 9600 baudrate which is not enough for DezuKVM to operate the keyboard and mouse emulation service smoothly. 
After the first time flashing (which now the device on board CH552G MCU contains an UUID and can be scanned by dezukvmd), following the steps below to change the CH9329 baudrate to 115200.

1. Power on the device by plugging the host side USB power cable into your computer
2. Connect the keyboard virtual machine (KVM) USB type C port (the one closer to the HDMI port for v6+ PCB) into a 5V power brick
3. Get and build dezukvmd and run `src/dezukvmd/configure_chip.sh` (If your CH340 that connects to the CH9329 was not on the expected default device path of `/dev/USBtty0`, you might want to modify `./config/usbkvm.json` relative to the dezukvmd binary executable to set a proper device path for your setup )
4. After the configure chip completed without error, unplug the KVM USB port (the one you plugged in on step 2)
5. Connect your remote computer (the computer that you want to control) to the KVM USB port and start dezukvmd or the usbkvm-app. Now you should be able to control the remote cursor and keyboard using your browser.

## Command List

### Protocol Notes
- **v1/v2**: Uses 3-byte protocol (operation type, subtype, payload)
- **v3/v4**: Uses length-prefixed commands (length + command + data)
- **v5+**: Uses single ASCII character commands

### Keyboard Commands
- `0x01` / `0x01`: Keyboard key press [v3+] (deprecated in v5)
- `0x02` / `0x02`: Keyboard key release [v3+] (deprecated in v5)
- `0x03` / `0x03`: Keyboard modifier key press [v3+] (deprecated in v5)
- `0x04` / `0x04`: Keyboard modifier key release [v3+] (deprecated in v5)

### Mouse Commands
- `0x05`: Mouse button press [v3+] (deprecated in v5)
- `0x06`: Mouse button release [v3+] (deprecated in v5)
- `0x07`: Mouse scroll up [v3+] (deprecated in v5)
- `0x08`: Mouse scroll down [v3+] (deprecated in v5)
- `0x09`: Mouse move absolute [v3+] (deprecated in v5)
- `0x0A`: Mouse move relative [v3+] (deprecated in v5)

### System Commands
- `0x0B`: Get keyboard LED status [v3+] (deprecated in v5)
- `0x00`: ATX power button press [v4+] (deprecated in v5)
- `0x01`: ATX power button release [v4+] (deprecated in v5)
- `0x02`: ATX reset button press [v4+] (deprecated in v5)
- `0x03`: ATX reset button release [v4+] (deprecated in v5)
- `0x04`: Get ATX LED status [v4+] (deprecated in v5)

### Simplified Commands (v5+)
- `1`: ATX power button press [v5] (deprecated in v6)
- `2`: ATX power button release [v5] (deprecated in v6)
- `3`: ATX reset button press [v5] (deprecated in v6)
- `4`: ATX reset button release [v5] (deprecated in v6)
- `5`: Switch USB mass storage to KVM [v5] (deprecated in v6)
- `6`: Switch USB mass storage to remote [v5] (deprecated in v6)

### Current Commands (v6+)
- `p`: ATX power button press [v6+]
- `s`: ATX power button release [v6+]
- `r`: ATX reset button press [v6+]
- `d`: ATX reset button release [v6+]
- `m`: Switch USB mass storage to KVM [v6+]
- `n`: Switch USB mass storage to remote [v6+]
- `u`: Get device UUID [v6+]
- `k`: Force reset HDMI capture card [v7+]
- `l`: Power off HDMI capture card [v7+]
- `j`: Power on HDMI capture card [v7+]
- `z`: Regenerate device UUID (debug only) [v6+]

## Changelog

### v7 (Latest)
- Added HDMI capture card power control and reset functionality
- New commands: 'k' (force reset HDMI), 'l' (power off HDMI), 'j' (power on HDMI)
- Added USB_HDMI_PWR pin for HDMI capture card management

### v6
- Introduced device UUID service for unique device identification
- Changed command set to single characters: 'p' (power press), 's' (power release), 'r' (reset press), 'd' (reset release), 'm' (USB MS to KVM), 'n' (USB MS to remote), 'u' (get UUID)
- Added optional ATX control with build flag ENABLE_ATX_CTRL
- Improved initialization with UUID setup

### v5
- Added USB mass storage switching with power control
- Implemented LED programming indicator for command feedback
- Added debug mode with build flag ENABLE_DEBUG
- Simplified command interface with numeric commands (1-6)
- Enhanced power switching delays for reliable USB MS operation

### v4
- Added ATX power and reset button control
- Implemented LED status reading for power and HDD indicators
- Increased UART baud rate to 19200 for better performance
- Added custom header bytes for RemdesKVM communication
- Introduced USB mass storage switch pin (currently unused)

### v3
- Switched to CH9329 chip for enhanced keyboard and mouse emulation
- Added keyboard LED status retrieval functionality
- Improved command processing with length-prefixed messages
- Added manufacturer and product string configuration
- Enhanced mouse support with absolute positioning

### v1/v2
- Initial firmware with basic USB HID keyboard and mouse emulation
- Implemented USB switch functionality for signal routing
- Basic serial communication protocol for KVM operations
- Support for keyboard writing, mouse movement, scrolling, and switching

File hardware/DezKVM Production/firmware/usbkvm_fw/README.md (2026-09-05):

# USB KVM Firmware - UART Operation Guide

This document describes how to operate the USB KVM device through UART serial communication.

## Connection Settings

- **Baud Rate**: 115200
- **Data Bits**: 8
- **Parity**: None
- **Stop Bits**: 1
- **Flow Control**: None

## Command Protocol

All commands are single ASCII characters sent over UART. The device responds with a binary protocol following this format:

```
<Length> <Command Identifier> <Payload>
```

**Note**: The Length byte includes only the Command Identifier and Payload bytes, not the Length byte itself.

## USB Mass Storage Commands

### Switch to KVM Host (`m`)
Switches the USB mass storage device to the KVM host side.

**Command**: `m` (0x6D)

**Usage**:
```
Send: m
```

### Switch to Remote PC (`n`)
Switches the USB mass storage device to the remote computer side.

**Command**: `n` (0x6E)

**Usage**:
```
Send: n
```

### Query USB Mass Storage Side (`y`)
Returns which side the USB mass storage is currently connected to.

**Command**: `y` (0x79)

**Usage**:
```
Send: y
Response: <Length> <Command ID> <Side>
```

## Device Identification

### Get Device UUID (`u`)
Returns the unique UUID (UUIDv4) of this KVM device.

**Command**: `u` (0x75)

**Response Format**:
```
<Length> 0x62 <UUID String>
```

**Example**:
```
Send: u
Response: 0x25 0x62 "ac1636c2-af4b-4241-8e2c-43e385c85602"
```

## ATX Power Control Commands

These commands are only available when `ENABLE_ATX_CTRL` is defined in the firmware.

### Report ATX Status (`a`)
Reports the current status of the ATX power and HDD LEDs.

**Command**: `a` (0x61)

**Response Format**:
```
0x02 0x61 <Status Byte>
```

The status byte contains the state of the power and HDD LEDs.

**Status Byte Format**:
- Bit 0: Power LED state (0 = OFF, 1 = ON)
- Bit 1: HDD LED state (0 = OFF, 1 = ON)
- Bits 2-7: Reserved

**Example Responses**:
```
Send: a
Response: 0x02 0x61 0x00  // Both LEDs off (PC is off)
Response: 0x02 0x61 0x01  // Power LED on, HDD LED off (PC is on, idle)
Response: 0x02 0x61 0x03  // Both LEDs on (PC is on, HDD active)
Response: 0x02 0x61 0x02  // Power LED off, HDD LED on (unusual state)
```

### Enable Automatic ATX Reporting (`i`)
Enables automatic reporting of ATX status changes.

**Command**: `i` (0x69)

**Usage**:
```
Send: i
```

After enabling, the device will automatically send ATX status updates when the power or HDD LED states change.

### Disable Automatic ATX Reporting (`o`)
Disables automatic reporting of ATX status changes.

**Command**: `o` (0x6F)

**Usage**:
```
Send: o
```

### Press Power Button (`p`)
Presses down the ATX power button (sets HIGH).

**Command**: `p` (0x70)

**Usage**:
```
Send: p
```

**Note**: You must release the button with the `s` command.

### Release Power Button (`s`)
Releases the ATX power button (sets LOW).

**Command**: `s` (0x73)

**Usage**:
```
Send: s
```

### Press Reset Button (`r`)
Presses down the ATX reset button (sets HIGH).

**Command**: `r` (0x72)

**Usage**:
```
Send: r
```

**Note**: You must release the button with the `d` command.

### Release Reset Button (`d`)
Releases the ATX reset button (sets LOW).

**Command**: `d` (0x64)

**Usage**:
```
Send: d
```

## LED Control Commands

Control the programmable LED (LED_PROG) on the device.

### LED Off (`0`)
Turns the programmable LED off.

**Command**: `0` (0x30)

**Usage**:
```
Send: 0
```

### LED On (`1`)
Turns the programmable LED on (solid).

**Command**: `1` (0x31)

**Usage**:
```
Send: 1
```

### LED Fast Blink (`2`)
Sets the LED to blink rapidly (200ms intervals).

**Command**: `2` (0x32)

**Usage**:
```
Send: 2
```

### LED Slow Blink (`3`)
Sets the LED to blink slowly (1000ms intervals).

**Command**: `3` (0x33)

**Usage**:
```
Send: 3
```

## System Commands

### Reset Echo (`f`)
Resets the communication and returns an acknowledgment.

**Command**: `f` (0x66)

**Response Format**:
```
0x01 0xFF
```

**Usage**:
```
Send: f
Response: 0x01 0xFF
```

## Error Responses

### Unknown Command (0xFE)
When an invalid command is sent, the device responds with:

```
0x01 0xFE
```

## Response Codes Summary

| Code | Description |
|---|---|
| 0xFE | Unknown command error |
| 0xFF | Reset echo acknowledgment |
| 0x60 | Reserved for future use |
| 0x61 | ATX status report |
| 0x62 | Device UUID |

## LED Behavior Notes

- **Default Mode**: By default (LED_MODE_AUTO), the LED toggles state each time a command is received
- **Manual Modes**: When using LED commands (`0`, `1`, `2`, `3`), the LED switches to manual control and stops auto-toggling
- **Startup Sequence**: On boot, the LED blinks 10 times rapidly to indicate initialization

## USB Mass Storage Switching

When switching the USB mass storage between KVM host and remote PC:

1. Power to the USB device is briefly cut
2. The data lines are switched
3. Power is restored with appropriate delays

**Delays**:
- Power switch delay: 100ms
- Data switch delay: 10ms

## ATX Control Notes

- The ATX control pins directly interface with the motherboard's front panel headers
- Button press commands (`p`, `r`) set the pins HIGH - you must remember to release them with (`s`, `d`)
- Typical power button press duration: 100-200ms for normal boot, 4-5 seconds for force shutdown
- Reset button press duration: 100-500ms

## Troubleshooting

**No response from device:**
- Check baud rate (should be 115200)
- Verify correct COM port / device path
- Ensure proper USB connection

**Commands not working:**
- Send reset echo command (`f`) and verify response (0x01 0xFF)
- Check if ENABLE_DEBUG was defined during compilation (not recommended for production)
- Verify ATX commands are only used when ENABLE_ATX_CTRL is defined

**LED not responding:**
- LED will not auto-toggle when in manual mode (`0`, `1`, `2`, `3` commands)
- Send LED command again to verify mode change

## Firmware Information

- **Target MCU**: CH552G
- **Clock Speed**: 24MHz (Internal)
- **Build Flags**:
  - `ENABLE_DEBUG`: Enable debug output (do not use in production)
  - `ENABLE_ATX_CTRL`: Enable ATX power control features

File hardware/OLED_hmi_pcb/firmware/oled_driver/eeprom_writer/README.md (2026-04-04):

# EEPROM Writer

This tool generates font bitmaps from a TrueType font and writes them — along with boot animation frames — to the OLED driver board's 24LC32 EEPROM (4096 bytes) via serial communication.

## Prerequisites

- Go 1.24.1 or later
- OLED driver board flashed with the latest firmware, connected via USB serial
- A TrueType font file (`.ttf`)

## Build

```bat
go build -o eeprom_write.exe
```

## Flashing the EEPROM

Use `write_eeprom.bat` to write both the font data and boot animation frames in one step.

**Before running**, open `write_eeprom.bat` and set the correct COM port and baud rate at the top:

```bat
set COM_PORT=COM5
set BAUDRATE=115200
```

Then run:

```bat
.\write_eeprom.bat
```

This will:
1. Write all 95 printable ASCII characters (0x20–0x7E) as 8×8 bitmaps using `protracker.ttf`
2. Write up to 3 boot animation frames from the `./bootanimation/` folder

## Write Modes

### Font mode (default)

Generates bitmaps for all printable ASCII characters and writes them to EEPROM.

```bat
.\eeprom_write.exe -port=COM5 -baudrate=115200 -font="protracker.ttf" -fontwidth=8 -fontheight=8 -fontsize=8 -offsetx=0 -offsety=1
```

Add `-nowrite` to generate and preview bitmaps in `./tmp/` without writing to EEPROM.

### Frame mode

Reads PNG images from `./bootanimation/`, converts them to SSD1306 page format, and writes them to EEPROM.

```bat
.\eeprom_write.exe -port=COM5 -baudrate=115200 -mode=frame
```

## Command Line Flags

| Flag | Default | Description |
|---|---|---|
| `-port` | `COM5` | Serial port |
| `-baudrate` | `115200` | Baud rate |
| `-mode` | `font` | Write mode: `font` or `frame` |
| `-font` | `./font.ttf` | Path to TrueType font file |
| `-fontwidth` | `16` | Glyph width in pixels |
| `-fontheight` | `16` | Glyph height in pixels |
| `-fontsize` | `14` | Font render size in points |
| `-offsetx` | `0` | Horizontal render offset |
| `-offsety` | `0` | Vertical render offset |
| `-tmpdir` | `./tmp` | Directory to save bitmap previews |
| `-nowrite` | `false` | Generate bitmaps only, skip EEPROM write |

## Test Scripts (`tests/`)

These scripts use the `eeprom_write.exe` from the parent directory. They are useful for previewing fonts or writing alternative fonts during development.

| Script | Description |
|---|---|
| `generate_default.bat` | Preview 16×16 font glyphs (`font.ttf`) without writing |
| `generate_dot_gothic.bat` | Preview 16×16 DotGothic16 glyphs without writing |
| `generate_protracker_8x8.bat` | Preview 8×8 Protracker glyphs without writing |
| `write_default.bat` | Write 16×16 `font.ttf` to EEPROM |
| `write_dot_gothic.bat` | Write 16×16 DotGothic16 to EEPROM |
| `write_protracker_8x8.bat` | Write 8×8 Protracker font to EEPROM |
| `write_bootanimation_frames.bat` | Write boot animation frames to EEPROM |

`generate_*` scripts add `-nowrite` so they produce bitmap previews in `./tmp/` only.

## EEPROM Layout

The 24LC32 has 4096 bytes total. Layout with 8×8 font (`FONT_CHAR_SIZE` = 8 bytes):

| Region | Address Range | Size |
|---|---|---|
| ASCII 0x20–0x7E font data (95 chars × 8 bytes) | 0x0000–0x02F7 | 760 bytes |
| Reserved / padding | 0x02F8–0x02FF | 8 bytes |
| Boot animation frames | 0x0300–0x0EFF | 3072 bytes |
| Unused | 0x0F00–0x0FFF | 256 bytes |

## Boot Animation Specifications

- **Image format:** PNG, monochrome (1-bit), converted via threshold (pixels darker than 50% grey = on)
- **Resolution:** exactly **128 × 64 pixels**
- **Storage format:** SSD1306 page format — 8 pages × 128 columns, 1 byte per column encodes 8 vertical pixels (LSB = topmost pixel of page)
- **Bytes per frame:** 1024
- **Maximum frames:** **3**
- **Frame addresses:**
  - Frame 0: `0x0300`–`0x06FF`
  - Frame 1: `0x0700`–`0x0AFF`
  - Frame 2: `0x0B00`–`0x0EFF`
- **Frame files:** place PNGs named in alphabetical order inside `./bootanimation/`. Files beyond the first 3 are ignored with a warning.

## LTV Protocol Commands

All serial packets use Length-Type-Value format. The length byte does not count itself.

| Command | Code | Packet Format |
|---|---|---|
| Write font to EEPROM | `0xC3` | `[len] [0xC3] [ascii] [N bytes font data]` |
| Read font from EEPROM | `0xC4` | `[0x02] [0xC4] [ascii]` → returns N raw bytes |
| Display font on OLED | `0xC5` | `[0x02] [0xC5] [ascii]` |
| Write raw EEPROM | `0xC6` | `[len] [0xC6] [addr_h] [addr_l] [data, max 32 bytes]` |
| Read raw EEPROM | `0xC7` | `[0x04] [0xC7] [addr_h] [addr_l] [count]` → returns count raw bytes |

On success the firmware responds with `0xF0`; on error `0xF1`.

## Troubleshooting

**Port not found:** Check Device Manager for the correct COM port and ensure CH552G drivers are installed.

**Freezes / no response:** The firmware's `CMD_MAX_LENGTH` buffer must be large enough for a full raw-write packet (36 bytes). Check that `oled_driver.h` defines `CMD_MAX_LENGTH` correctly.

**Characters look wrong:** Adjust `-fontsize`, `-offsetx`, `-offsety` flags, or use `-nowrite` to preview in `./tmp/` first.

**Animation colours inverted:** The tool bitwise-inverts (`^b`) all frame bytes before writing so that black PNG pixels illuminate OLED pixels. If the display is still inverted, check `loadAndConvertFrame()` in `main.go`.

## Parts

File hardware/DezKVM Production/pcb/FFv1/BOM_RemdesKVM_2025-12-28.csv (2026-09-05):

ID | Name | Designator | Footprint | Quantity | Manufacturer Part | Manufacturer | Supplier | Supplier Part | Price
1 | 0805G (Green) | ACT,UP_LED | LED0805-R-RD | 2 | KT-0805G | KENTO | LCSC | C2297 | 0.011
2 | whiteLEDSMD | PROGLED1,PWR_LED | LED0805-R-RD | 2 | KT-0805W | KENTO | LCSC | C34499 | 0.019
3 | CH552G | ATXCTRL | SOP-16_L10.0-W3.9-P1.27-LS6.0-BL | 1 | CH552G | WCH(南京沁恒) | LCSC | C111292 | 0.6
4 | CH340C | CH340C | SOP-16_L10.0-W3.9-P1.27-LS6.0-BL | 1 | CH340C | WCH(南京沁恒) | LCSC | C84681 | 0.543
5 | CH440G | USBMS-SW | SOP-16_L10.0-W3.9-P1.27-LS6.0-BL | 1 | CH440G | WCH(南京沁恒) | LCSC | C88324 | 0.491
6 | SL2.1A | US_HUB | SOP-16_L10.0-W3.9-P1.27-LS6.0-BL | 1 | SL2.1A | CoreChips(和芯润德) | LCSC | C192893 | 0.228
7 | 10uF | C1,C2,C7,C8 | C0805 | 4 | CL21A106KAYNNNE | SAMSUNG(三星) | LCSC | C15850 | 0.011
8 | 100nF | C3,C4,C5,C6,C9,C10,C11 | C0805 | 7 | CC0805KRX7R9BB104 | YAGEO(国巨) | LCSC | C49678 | 0.005
9 | 1uF | C12 | C0805 | 1 | CL21B105KBFNNNE | SAMSUNG(三星) | LCSC | C28323 | 0.009
10 | TS-1187A-B-A-B | FLASH | SW-SMD_4P-L5.1-W5.1-P3.70-LS6.5-TL_H1.5 | 1 | TS-1187A-B-A-B | XKB Connectivity(中国星坤) | LCSC | C318884 | 0.02
11 | EL817S1(C)(TU)-F | HDD_LED1,PWR_LED1,PWR_OCT1,RST_OCT1 | OPTO-SMD-4_L4.6-W6.5-P2.54-LS10.3-TL | 4 | EL817S1(C)(TU)-F | EVERLIGHT(亿光) | LCSC | C106900 | 0.044
12 | KH-AF90QCSMT-10-H6.3 | USB_STICK | USB-A-SMD_KH-AF90QCSMT-10-H6.3 | 1 | KH-AF90QCSMT-10-H6.3 | kinghelm(金航标) | LCSC | C2979063 | 0.025
13 | 1*4P 2.54MM | PROG | HDR-TH_4P-P2.54-V-C4_TH-4_2.5X10.5X2.54P | 1 | 单排直插排针 1*4P 2.54mm | null | LCSC | C2887121
14 | AO3401A | Q1 | SOT-23_L2.9-W1.3-P1.90-LS2.4-BR | 1 | AO3401A | AOS | LCSC | C15127 | 0.055
15 | AO3400A | Q2 | SOT-23-3_L2.9-W1.3-P1.90-LS2.4-BR | 1 | AO3400A | AOS | LCSC | C20917 | 0.074
16 | 5.1kΩ | R1,R2,R9,R13,R14,R15,R19,R24 | R0805 | 8 | 0805W8F5101T5E | UNI-ROYAL(厚声) | LCSC | C27834 | 0.002
17 | 10kΩ | R3,R4,R7,R8,R10,R20,R25 | R0805 | 7 | 0805W8F1002T5E | UNI-ROYAL(厚声) | LCSC | C17414 | 0.002
18 | 1kΩ | R5,R6,R12 | R0805 | 3 | 0805W8F1001T5E | UNI-ROYAL(厚声) | LCSC | C17513 | 0.002
19 | 330Ω | R11,R16 | R0805 | 2 | 0805W8F3300T5E | UNI-ROYAL(厚声) | LCSC | C17630 | 0.002
20 | 0Ω | R17,R18,R20/NC,R21,R22/NC,R23/NC | R0805 | 6 | 0805W8F0000T5E | UNI-ROYAL(厚声) | LCSC | C17477 | 0.002
21 | CH9329 | U1 | SOP-16_L9.9-W3.9-P1.27-LS6.0-BL | 1 | CH9329 | WCH(南京沁恒) | LCSC | C2838834 | 1.2
22 | USB3.1C16PFSMT | USB-HOST,USBHID,USBMS | USB-C-SMD_TYPE-C-USB-17 | 3 | 918-418K2023S40001 | 精拓金 | LCSC | C167321 | 0.362
23 | XH2.54-4P- 直插 | USB_UP | CONN-TH_4P-P2.50-XH2.54-4P | 1 | XH2.54-4P- 直插 | null | LCSC | C9900000103
24 | 12MHz | X2 | OSC-SMD_L5.0-W3.2 | 1 | X503212MSD2GI | YXC(扬兴晶振) | LCSC | C114436 | 0.22
25 | HDR-TH_4P-P2.54-V-M | U6,U7,U9 | HDR-TH_4P-P2.54-V-M | 3

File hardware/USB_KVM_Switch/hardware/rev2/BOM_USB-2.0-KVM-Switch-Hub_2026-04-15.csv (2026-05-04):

ID | Name | Designator | Footprint | Quantity | Manufacturer Part | Manufacturer | Supplier | Supplier Part | Price
1 | 10uF | C1,C2,C3,C4,C7 | C0805 | 5 | CL21A106KAYNNNE | SAMSUNG(三星) | LCSC | C15850 | 0.022
2 | 100nF | C5,C6,C8 | C0805 | 3 | CC0805KRX7R9BB104 | YAGEO(国巨) | LCSC | C49678 | 0.005
3 | 2.54-1*4P母 | EXT_CONN1 | HDR-TH_4P-P2.54-V-F | 1 | 2.54-1*4P母 | BOOMELE(博穆精密) | LCSC | C2718488 | 0.078
4 | TS-1187A-B-A-B | FLASH | SW-SMD_4P-L5.1-W5.1-P3.70-LS6.5-TL_H1.5 | 1 | TS-1187A-B-A-B | XKB Connectivity(中国星坤) | LCSC | C318884 | 0.02
5 | whiteLEDSMD | HOST1_LED,HOST2_LED | LED0805-R-RD | 2 | KT-0805W | KENTO | LCSC | C34499 | 0.02
6 | 1*4P 2.54MM | PROG1 | HDR-TH_4P-P2.54-V-C4_TH-4_2.5X10.5X2.54P | 1 | 单排直插排针 1*4P 2.54mm | null | LCSC | C2887121
7 | AO3400_C50176479 | Q1 | SOT-23-3_L2.9-W1.6-P1.90-LS2.8-BR | 1 | AO3400 | SEP(威旺) | LCSC | C50176479 | 0.02
8 | 5.1kΩ | R1,R2,R14,R15 | R0805 | 4 | 0805W8F5101T5E | UNI-ROYAL(厚声) | LCSC | C27834 | 0.003
9 | 10kΩ | R3,R10 | R0805 | 2 | 0805W8F1002T5E | UNI-ROYAL(厚声) | LCSC | C17414 | 0.003
10 | 1kΩ | R4,R5,R6,R12 | R0805 | 4 | 0805W8F1001T5E | UNI-ROYAL(厚声) | LCSC | C17513 | 0.003
11 | 0Ω | R7,R8 | R0805 | 2 | YLRY05-W2-0Z | yezhan(业展) | LCSC | C22468035 | 0.039
12 | TS-1102SD-A-L-R | SW1 | SW-SMD_4P-L6.0-W6.0-P4.50-LS9.2 | 1 | TS-1102SD-A-L-R | XKB Connection(中国星坤) | LCSC | C3010212 | 0.054
13 | CH552G | SWITCH_MCU | SOP-16_L10.0-W3.9-P1.27-LS6.0-BL | 1 | CH552G | WCH(南京沁恒) | LCSC | C111292 | 0.88
14 | CH440G | USB-SW | SOP-16_L10.0-W3.9-P1.27-LS6.0-BL | 1 | CH440G | WCH(南京沁恒) | LCSC | C88324 | 0.504
15 | SL2.1A | USB_HUB1,USB_HUB2 | SOP-16_L10.0-W3.9-P1.27-LS6.0-BL | 2 | SL2.1A | CoreChips(和芯润德) | LCSC | C192893 | 0.236
16 | 5V 3A DC | U1 | DC-IN-TH_HC-DC-007B-2.5 | 1 | HC-DC-007B-2.5 | HCTL(华灿天禄) | LCSC | C3010538 | 0.491
17 | LM66100DCKR | U3,U4 | SC-70-6_L2.0-W1.3-P0.65-LS2.1-BL | 2 | LM66100DCKR | TI(德州仪器) | LCSC | C2869734 | 0.209
18 | HDMI_SW_EN | U10 | HDR-TH_2P-P2.54-V-F-4 | 1 | 254PM-1x2P-V | LXWCONN(连兴旺电子) | LCSC | C53202175 | 0.086
19 | USB3.1C16PFSMT | USB-HOST1,USB-HOST2 | USB-C-SMD_TYPE-C-USB-17 | 2 | 918-418K2023S40001 | 精拓金 | LCSC | C167321 | 0.398
20 | KH-AF90QCSMT-10-H6.3 | USB_PORT2,USB_PORT3,USB_PORT4,USB_PORT5,USB_PORT6,USB_PORT7 | USB-A-SMD_KH-AF90QCSMT-10-H6.3 | 6 | KH-AF90QCSMT-10-H6.3 | kinghelm(金航标) | LCSC | C2979063 | 0.025
21 | 12MHz | X1,X2 | OSC-SMD_L5.0-W3.2 | 2 | X503212MSD2GI | YXC(扬兴晶振) | LCSC | C114436 | 0.22

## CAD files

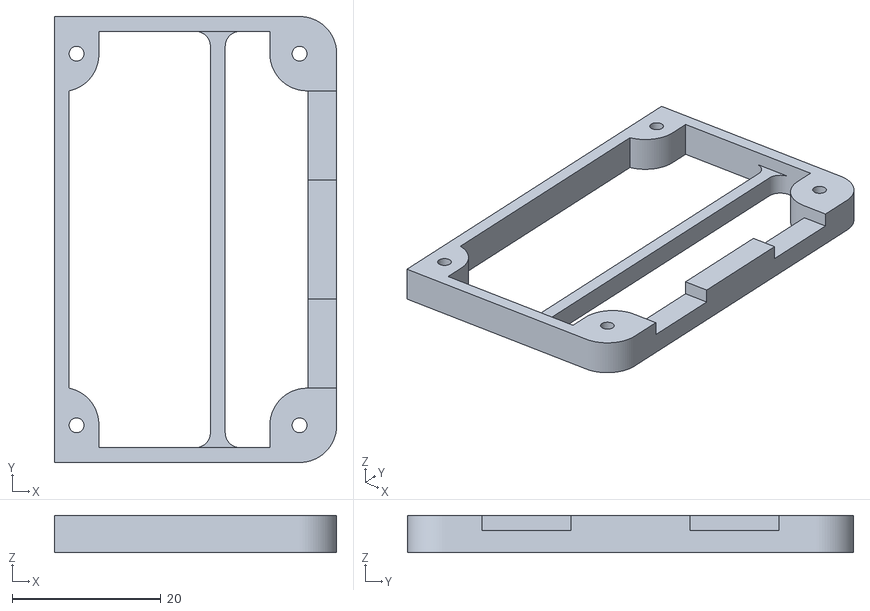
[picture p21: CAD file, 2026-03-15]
hardware/ATX board/3d_models/atx-adapter_cable-press.stl
38.0 x 60.0 x 5.00

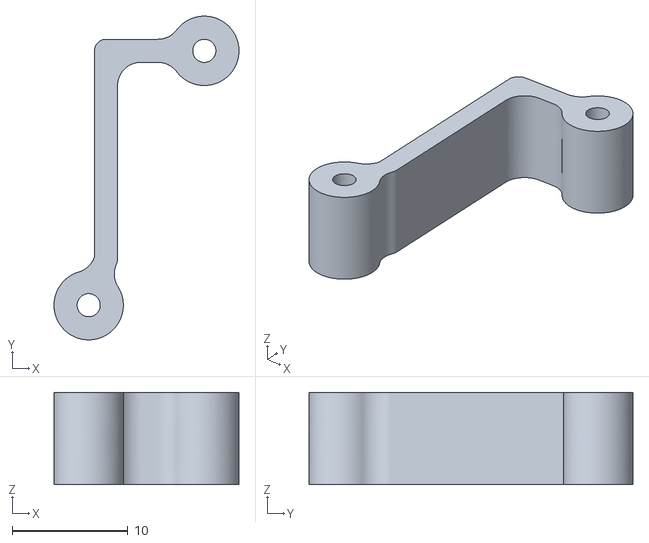
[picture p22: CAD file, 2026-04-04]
hardware/DezKVM PoC/3d_models/back.stl
16.0 x 28.0 x 8.00

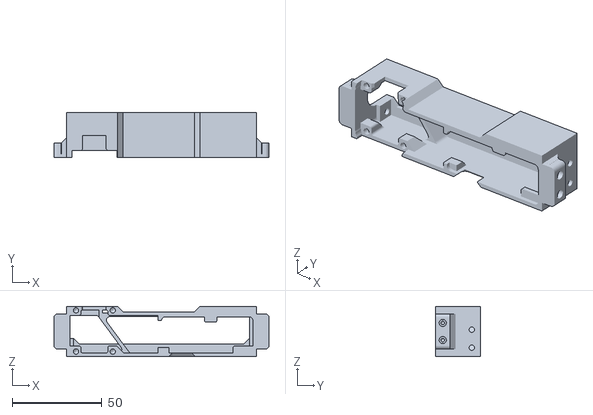
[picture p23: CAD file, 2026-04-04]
hardware/DezKVM Production/3d_models/PFF_single_port/display_components.stl
119.8 x 25.0 x 28.0

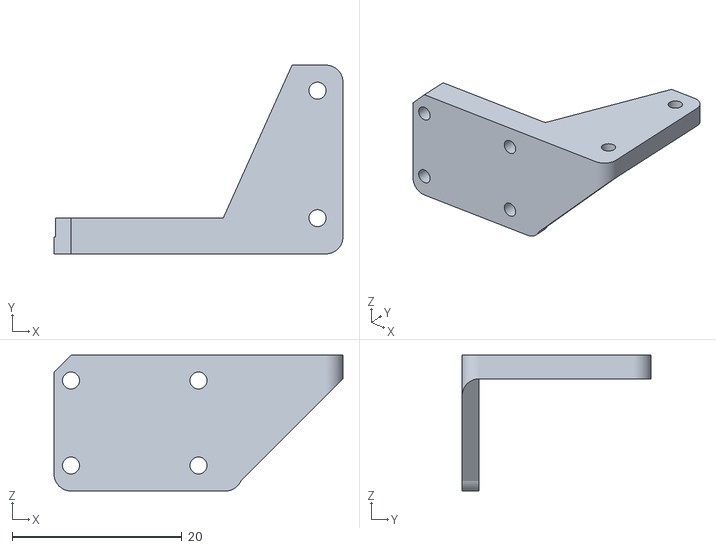
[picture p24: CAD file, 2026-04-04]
hardware/DezKVM Production/3d_models/PFF_v1_base/bridge_structure_B.stl
34.0 x 22.2 x 16.0

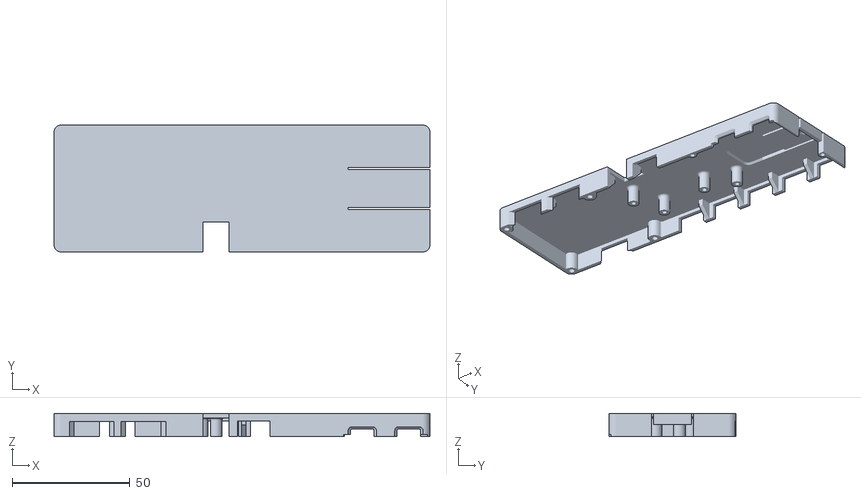
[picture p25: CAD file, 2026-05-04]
hardware/USB_KVM_Switch/3D models/cover.stl
160.0 x 54.0 x 10.0

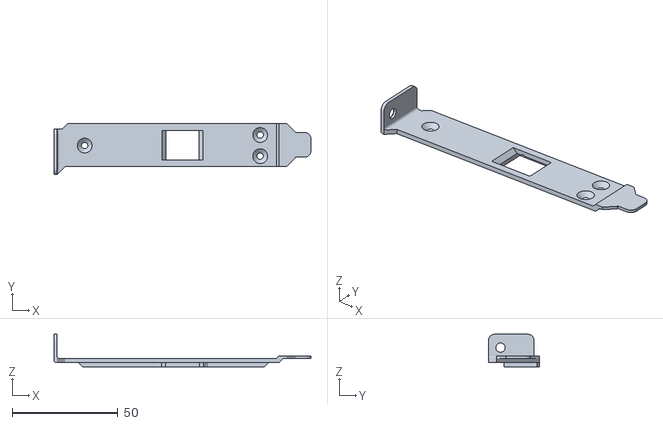
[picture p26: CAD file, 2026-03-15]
hardware/ATX board/3d_models/pcie-bracket.stl
121.5 x 24.1 x 15.4

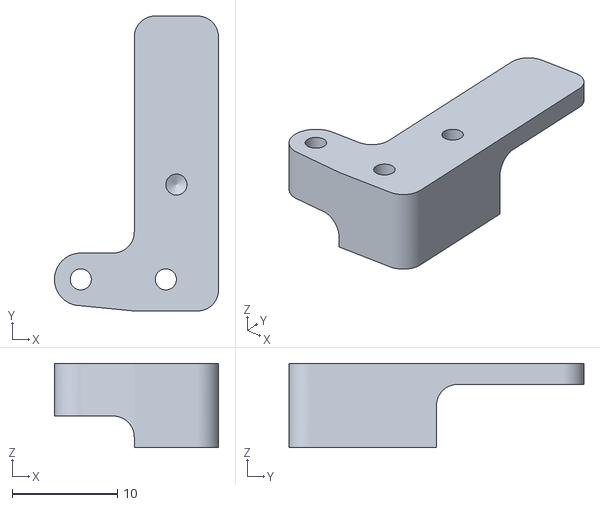
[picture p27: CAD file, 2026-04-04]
hardware/DezKVM PoC/3d_models/front.stl
15.6 x 28.0 x 8.00

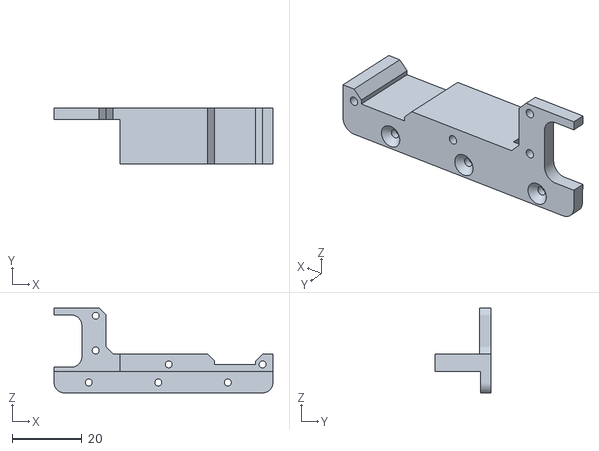
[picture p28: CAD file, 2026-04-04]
hardware/DezKVM Production/3d_models/PFF_single_port/bridge_structure_A.stl
63.0 x 16.0 x 24.4

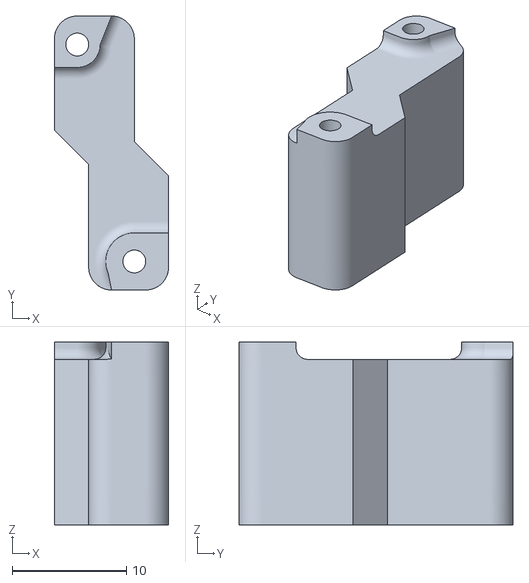
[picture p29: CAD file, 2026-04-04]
hardware/DezKVM Production/3d_models/PFF_v1_base/bridge_structure_C.stl
10.0 x 24.0 x 16.0

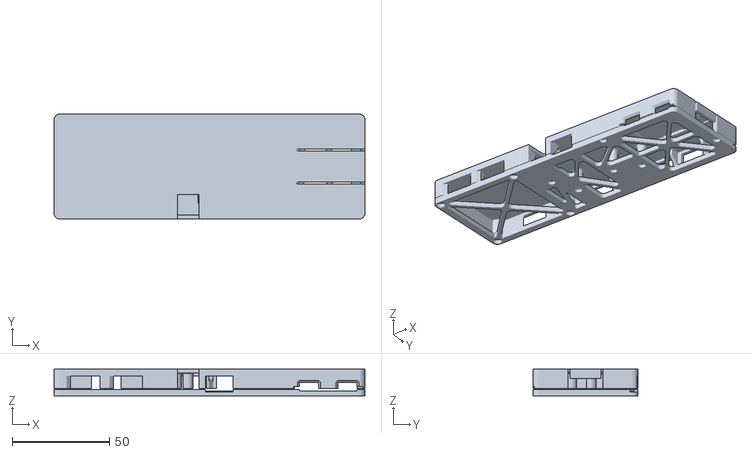
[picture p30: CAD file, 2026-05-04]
hardware/USB_KVM_Switch/3D models/test-fit.stl
160.0 x 54.0 x 13.7

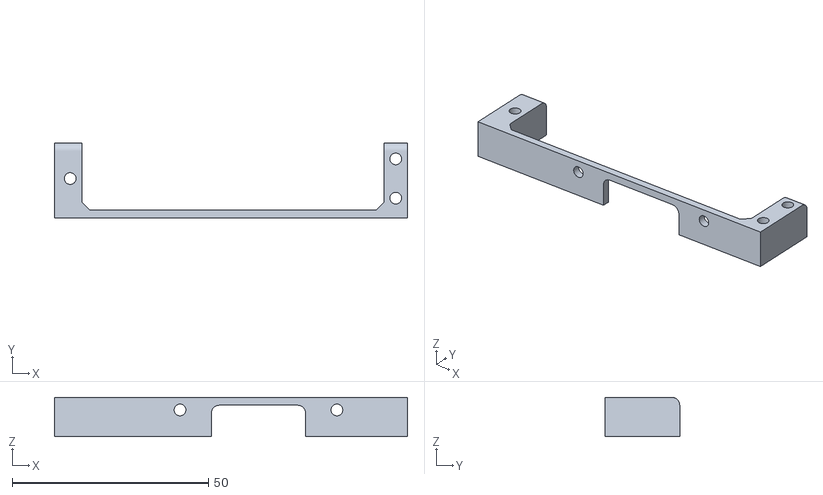
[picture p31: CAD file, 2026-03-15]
hardware/ATX board/3d_models/atx-adapter_mount.stl
90.0 x 19.0 x 10.0

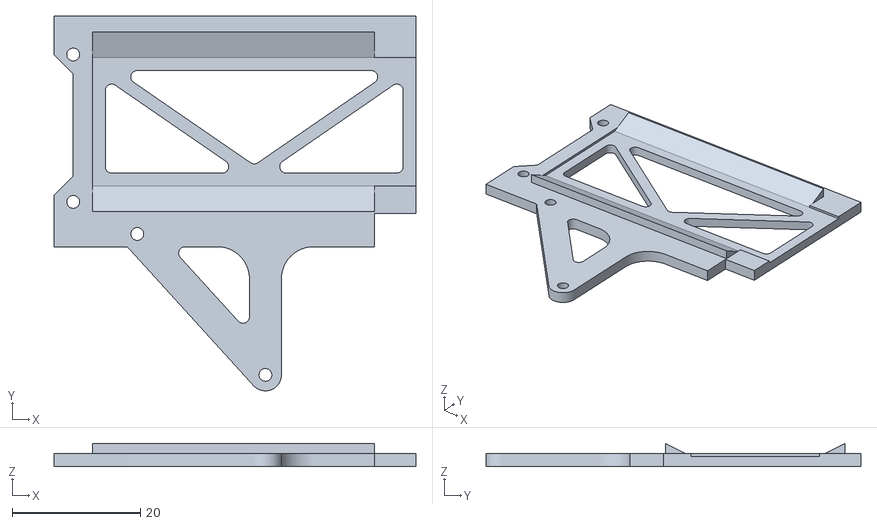
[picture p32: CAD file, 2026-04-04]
hardware/DezKVM PoC/3d_models/capture_holder_bottom.stl
56.5 x 58.5 x 3.60

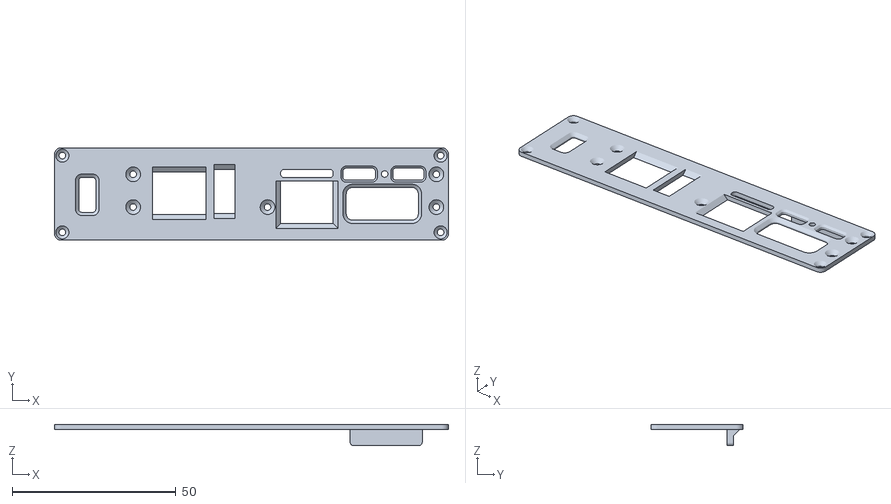
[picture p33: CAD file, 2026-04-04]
hardware/DezKVM Production/3d_models/PFF_single_port/back_panel.stl
120.2 x 28.2 x 6.50

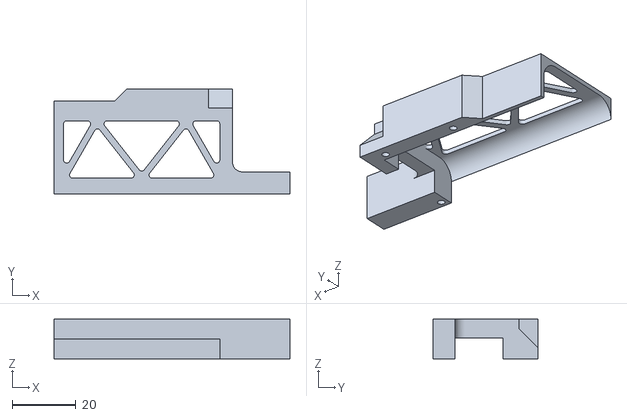
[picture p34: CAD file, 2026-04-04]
hardware/DezKVM Production/3d_models/PFF_v1_base/hdmi_holder.stl
74.0 x 33.0 x 12.5

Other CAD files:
hardware/USB_KVM_Switch/3D models/cover_no-hdmi.stl
hardware/DezKVM PoC/3d_models/capture_holder_bottom_filled.stl
hardware/DezKVM Production/3d_models/PFF_single_port/front-panel.stl
hardware/DezKVM Production/3d_models/PFF_v1_base/bridge_structure_A.stl
hardware/ATX board/3d_models/atx-adapter_cable-press.ipt
hardware/ATX board/3d_models/atx-adapter_mount.ipt
hardware/ATX board/3d_models/pcie-bracket.ipt
hardware/ATX board/3d_models/test_fit.iam
hardware/DezKVM PoC/3d_models/back.ipt
hardware/DezKVM PoC/3d_models/capture_holder_bottom.ipt
hardware/DezKVM PoC/3d_models/capture_holder_bottom_filled.ipt
hardware/DezKVM PoC/3d_models/capture_holder_top.ipt
hardware/DezKVM PoC/3d_models/capture_holder_top.stl
hardware/DezKVM PoC/3d_models/front.ipt
hardware/DezKVM Production/3d_models/PFF_single_port/OldVersions/back_panel.0026.ipt
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

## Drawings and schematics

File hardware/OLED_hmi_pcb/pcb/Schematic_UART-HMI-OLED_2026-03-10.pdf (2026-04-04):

# VBUS A4 CC1 A5 DP1 A6 DN1 A7 SBU1 A8 VBUS A9

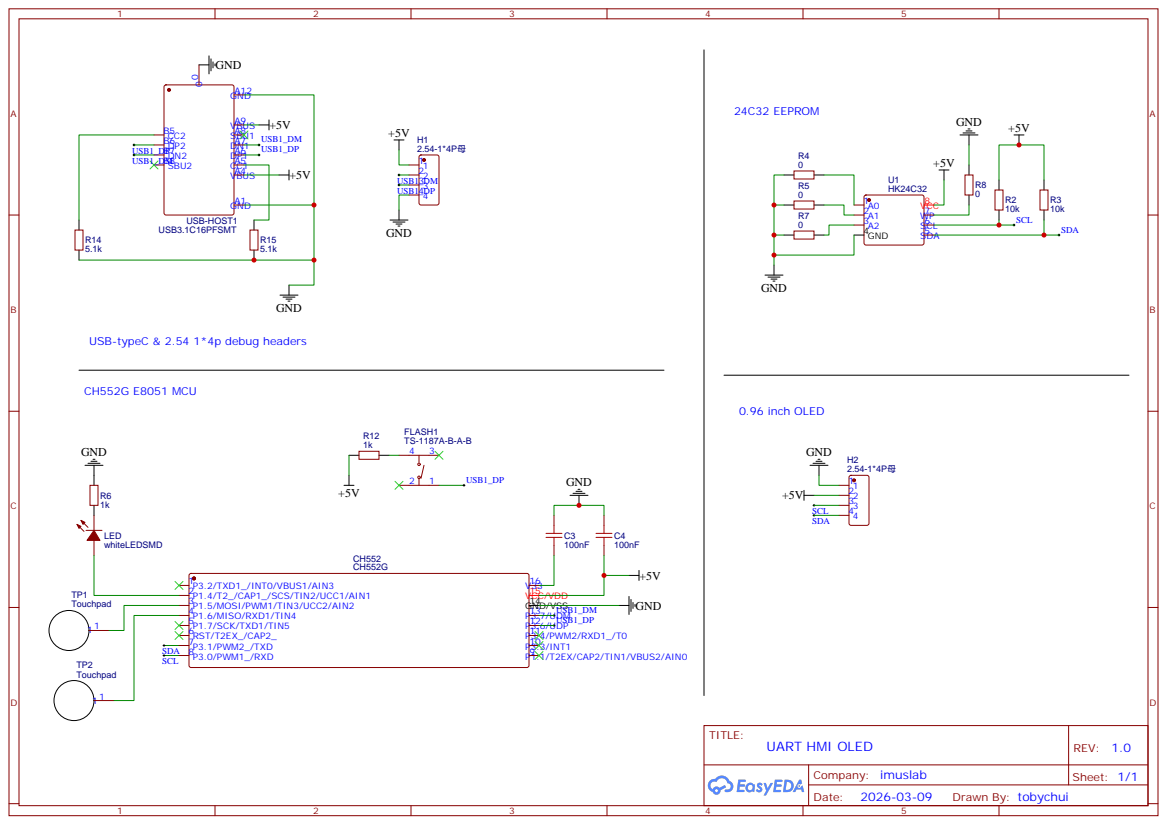
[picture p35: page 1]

USB-typeC & 2.54 1*4p debug headers

P3.3/INT1 10 P3.4/PWM2/RXD1_/T0 11 P3.6/UDP 12 P3.7/UDM 13 GND/VSS 14 VCC/VDD 15 V33 16

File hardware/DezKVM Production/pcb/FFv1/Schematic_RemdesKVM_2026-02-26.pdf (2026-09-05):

## Upstream USB Port Power Ripple Filter

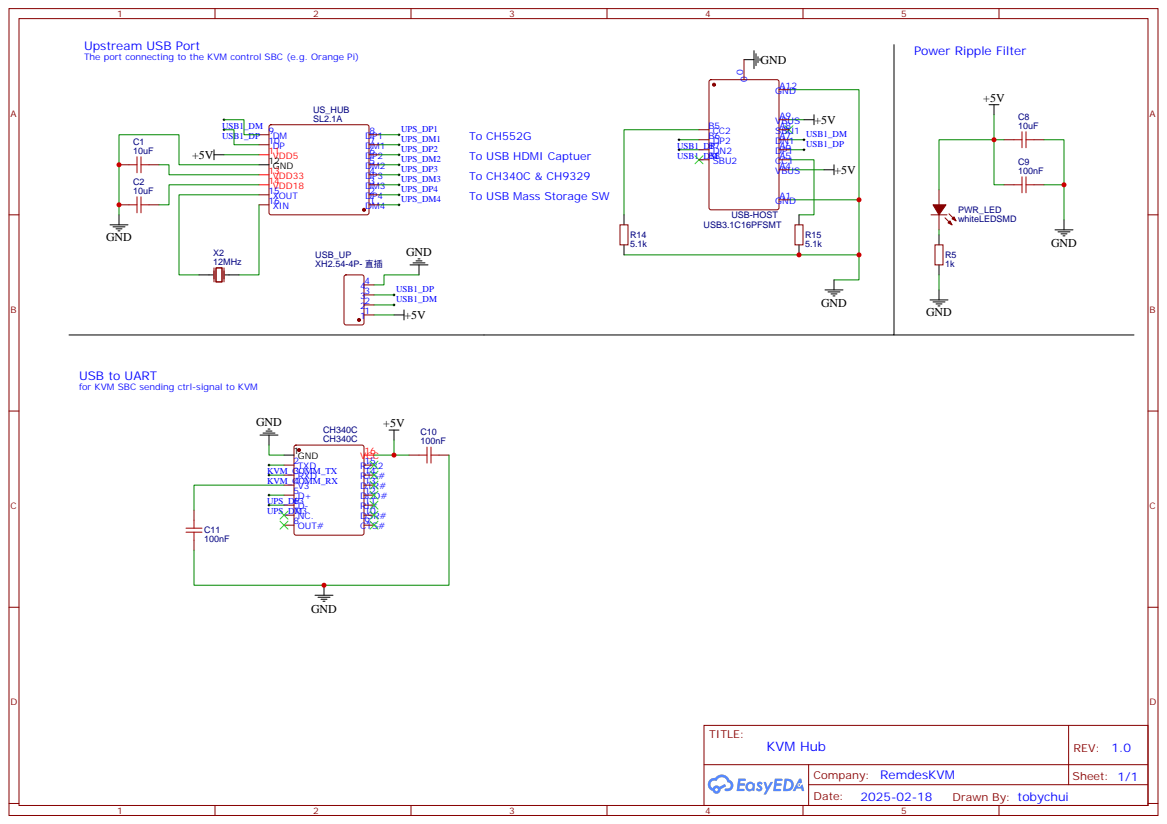
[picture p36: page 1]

The port connecting to the KVM control SBC (e.g. Orange Pi)

To USB HDMI Captuer
To USB Mass Storage SW

USB to UART
for KVM SBC sending ctrl-signal to KVM

DSR# 10 RI#11 DCD# 12 DTR# 13 RTS# 14 R232 15 VCC 16

## USB HDMI Capture Card

# DEF 10 SET 11 UD+ 12 UD- 13 GND 14 VCC 15 V33 16

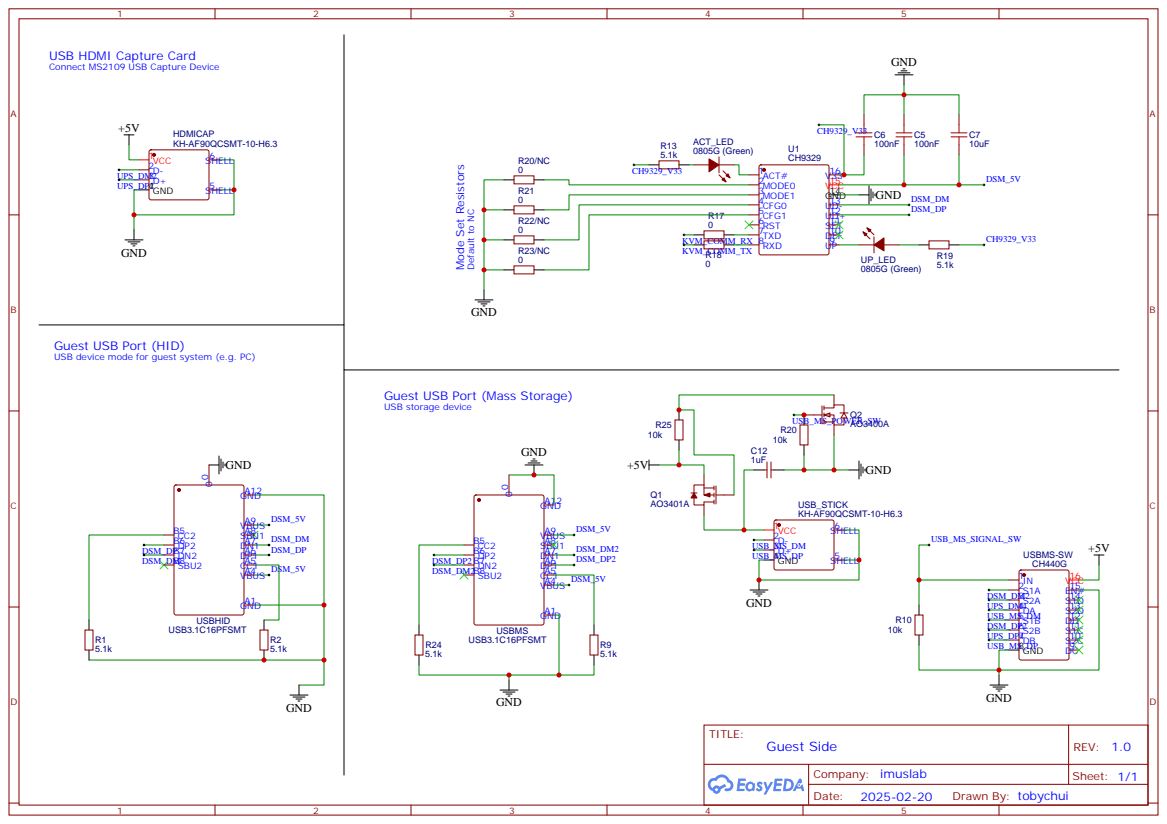
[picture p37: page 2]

Connect MS2109 USB Capture Device

Guest USB Port (HID)
USB device mode for guest system (e.g. PC)

Guest USB Port (Mass Storage)
USB storage device

## ATX Power Control

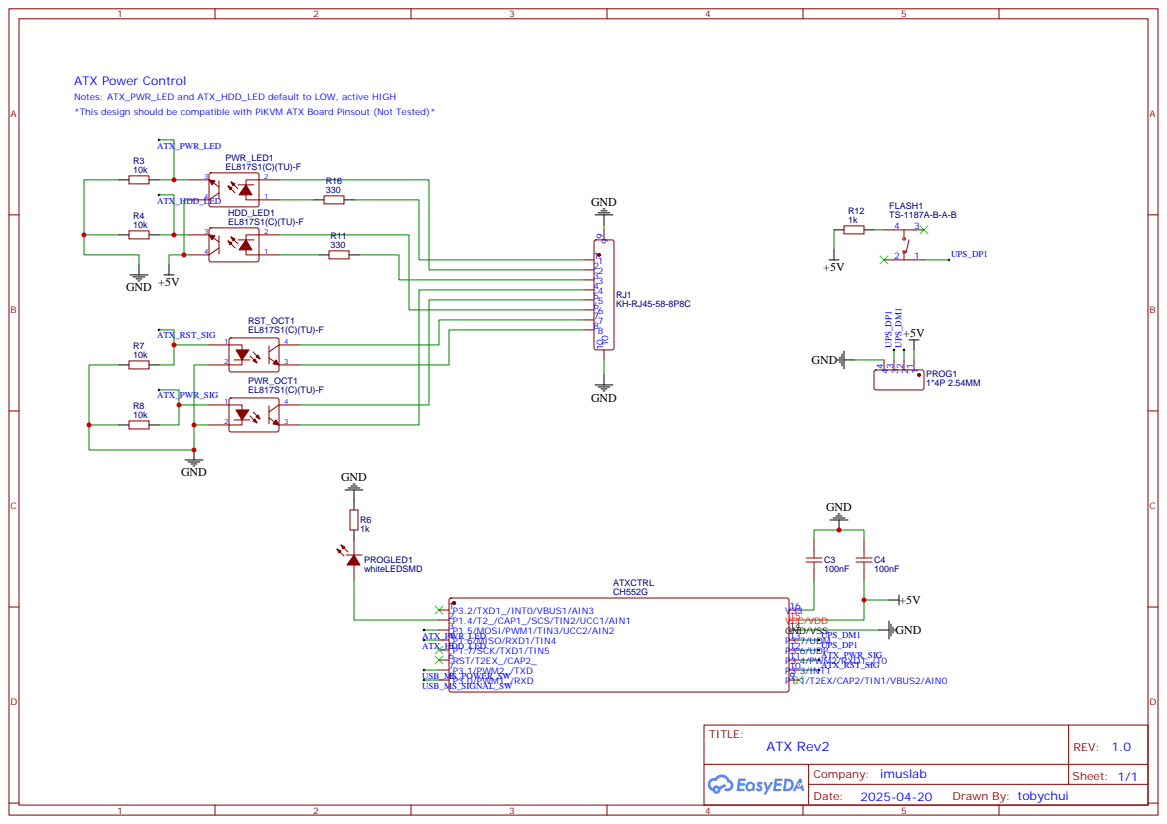
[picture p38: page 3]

Notes: ATX_PWR_LED and ATX_HDD_LED default to LOW, active HIGH
*This design should be compatible with PiKVM ATX Board Pinsout (Not Tested)*

P3.3/INT1 10 P3.4/PWM2/RXD1_/T0 11 P3.6/UDP 12 P3.7/UDM 13 GND/VSS 14 VCC/VDD 15 V33 16

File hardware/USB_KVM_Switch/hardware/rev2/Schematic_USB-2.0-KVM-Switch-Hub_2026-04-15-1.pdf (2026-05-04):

# VBUS A4 CC1 A5 DP1 A6 DN1 A7 SBU1 A8 VBUS A9

## Host 1 USB Port

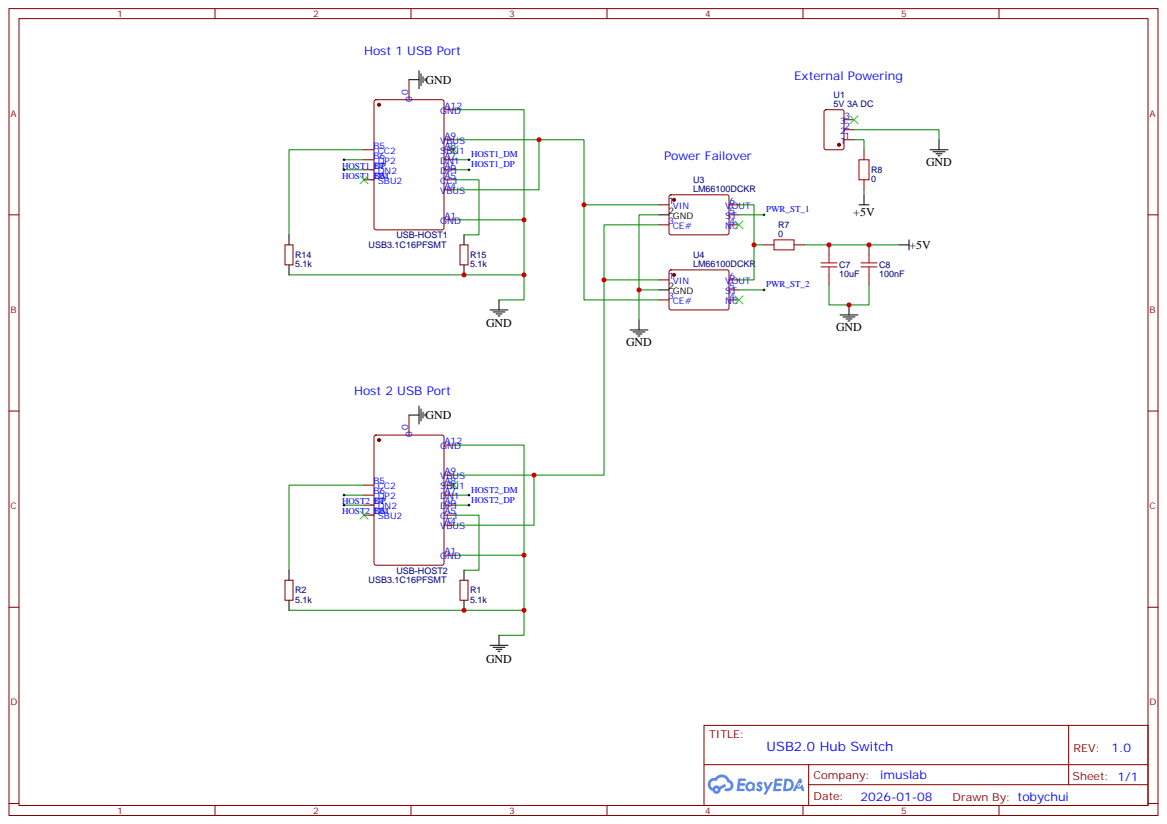
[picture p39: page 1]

## USB Ports (Primary Hub)

## Upstream Hub

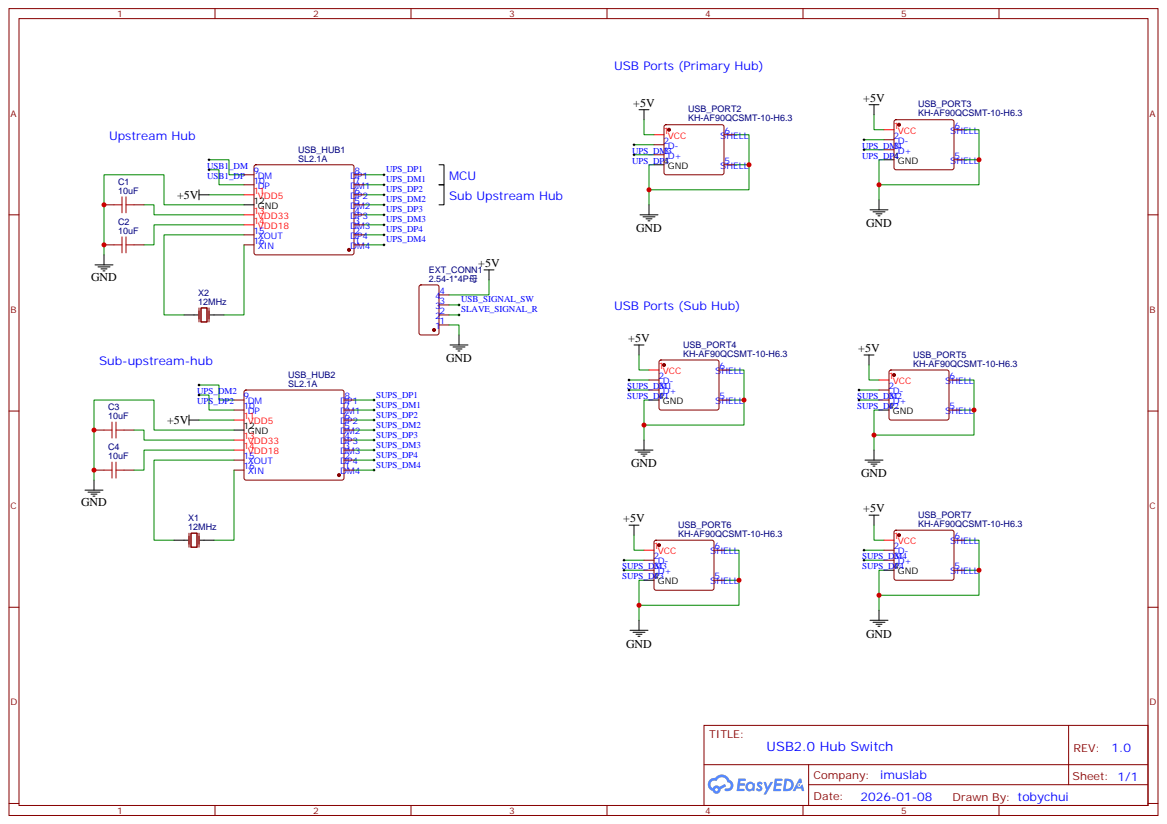
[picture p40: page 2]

USB Ports (Sub Hub)

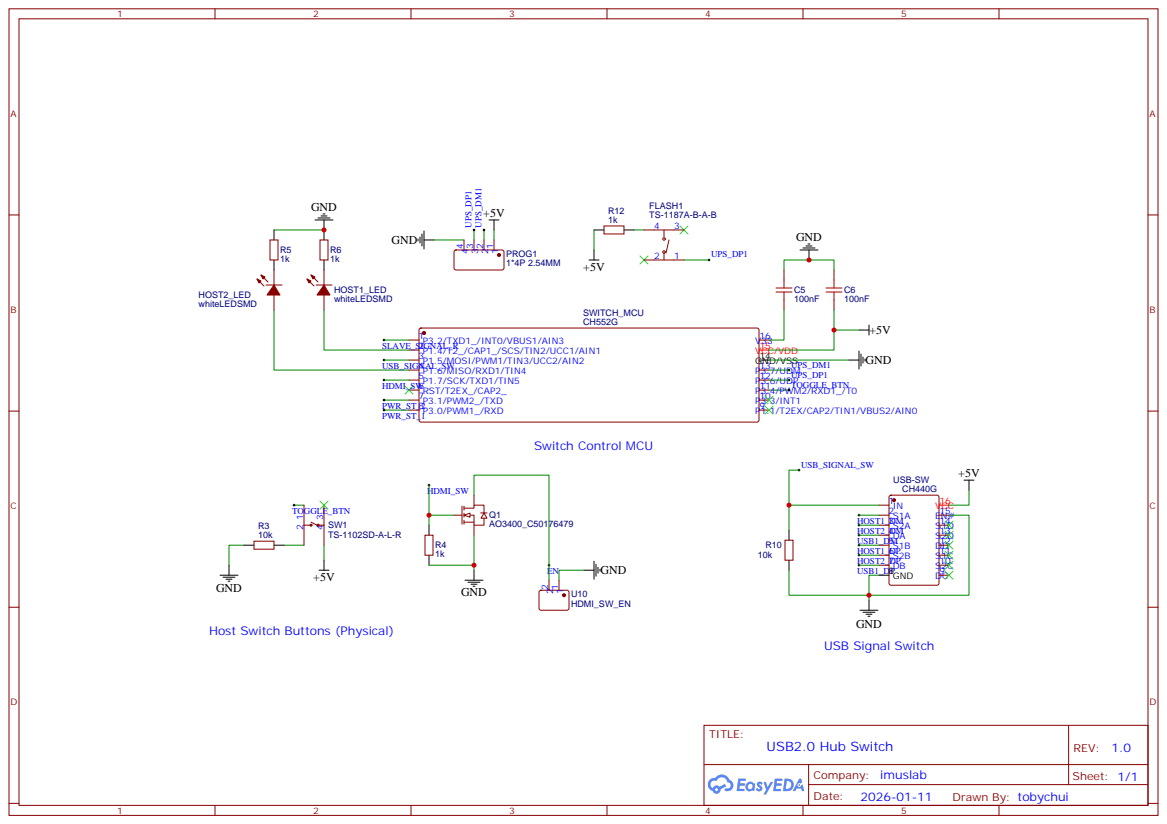
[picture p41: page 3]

P3.3/INT1 10 P3.4/PWM2/RXD1_/T0 11 P3.6/UDP 12 P3.7/UDM 13 GND/VSS 14 VCC/VDD 15 V33 16

Host Switch Buttons (Physical)

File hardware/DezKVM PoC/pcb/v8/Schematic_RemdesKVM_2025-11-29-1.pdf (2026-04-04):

## Upstream USB Port Power Ripple Filter

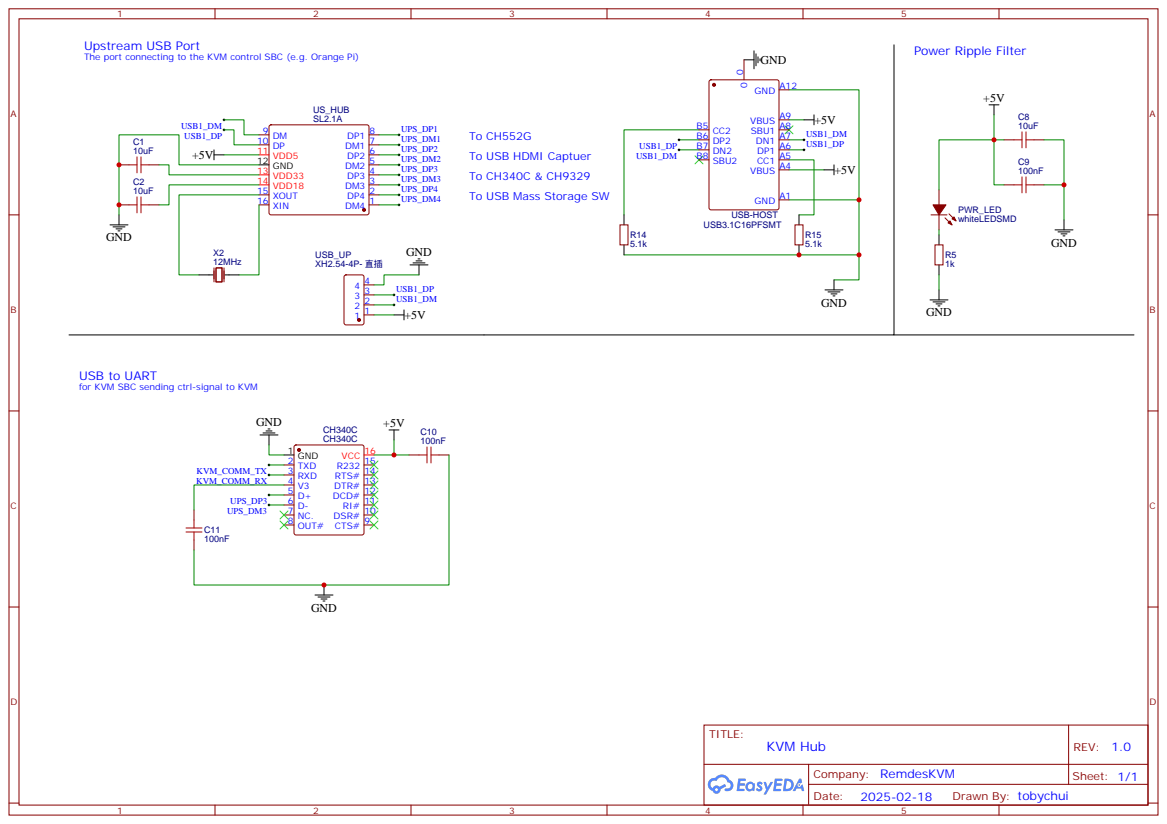
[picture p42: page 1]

The port connecting to the KVM control SBC (e.g. Orange Pi)

To USB HDMI Captuer
To USB Mass Storage SW

USB to UART
for KVM SBC sending ctrl-signal to KVM

DSR# 10 RI# 11 DCD# 12 DTR# 13 RTS# 14 R232 15 VCC 16

## USB HDMI Capture Card

# DEF 10 SET 11 UD+ 12 UD- 13 GND 14 VCC 15 V33 16

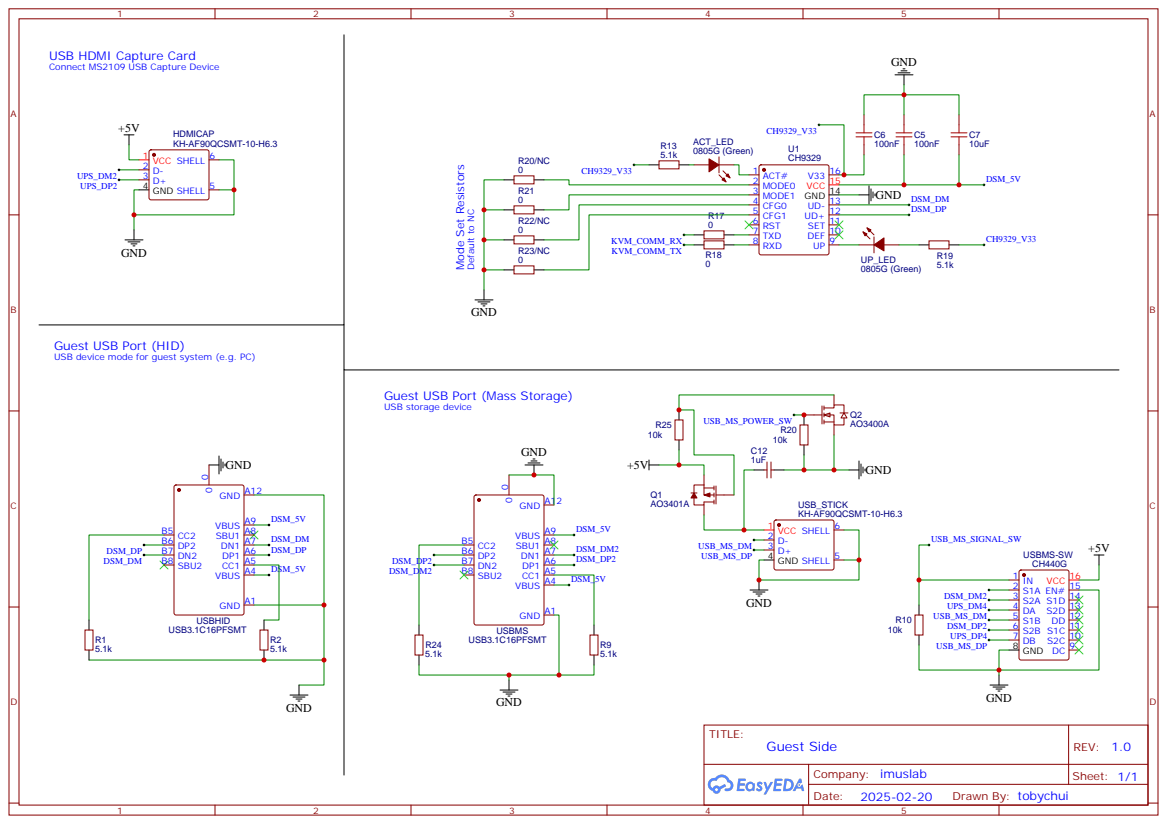
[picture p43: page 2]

Connect MS2109 USB Capture Device

Guest USB Port (HID)
USB device mode for guest system (e.g. PC)

Guest USB Port (Mass Storage)
USB storage device

## ATX Power Control

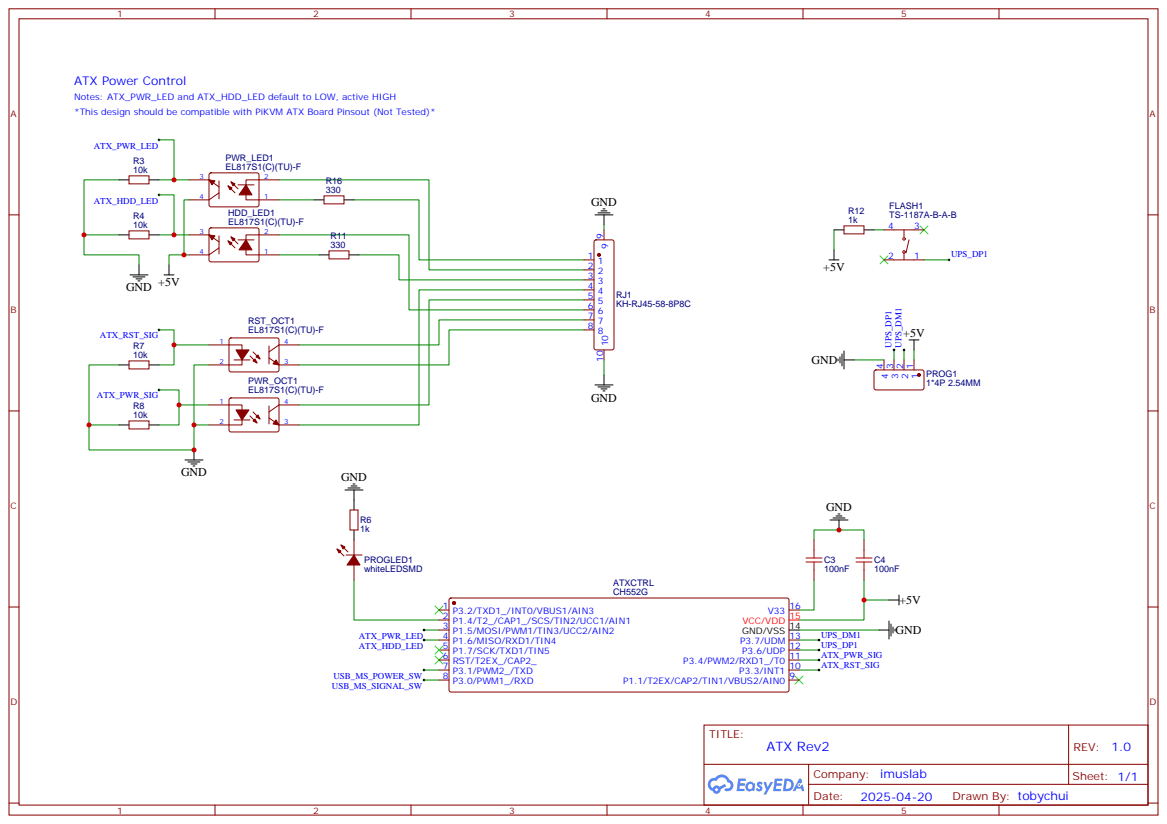
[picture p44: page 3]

Notes: ATX_PWR_LED and ATX_HDD_LED default to LOW, active HIGH
*This design should be compatible with PiKVM ATX Board Pinsout (Not Tested)*

P3.3/INT1 10 P3.4/PWM2/RXD1_/T0 11 P3.6/UDP 12 P3.7/UDM 13 GND/VSS 14 VCC/VDD 15 V33 16

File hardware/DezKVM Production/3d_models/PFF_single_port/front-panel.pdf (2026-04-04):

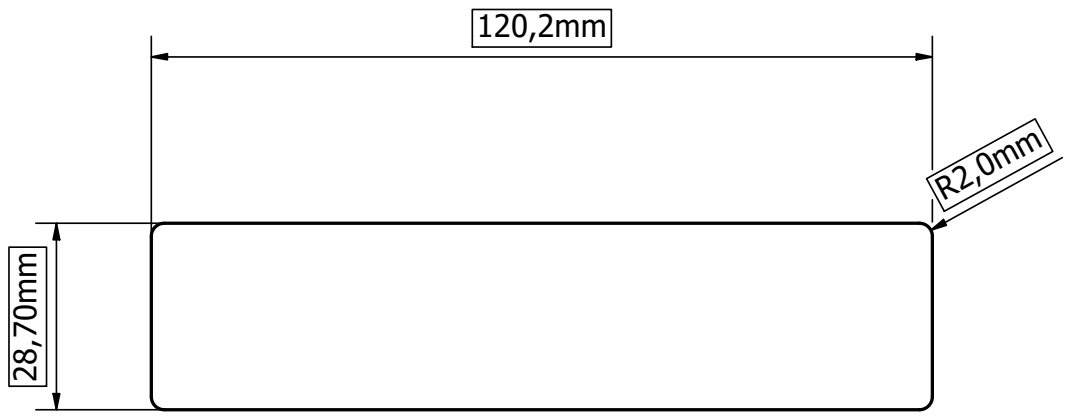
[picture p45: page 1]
Designed by; Checked by; Approved by; Date

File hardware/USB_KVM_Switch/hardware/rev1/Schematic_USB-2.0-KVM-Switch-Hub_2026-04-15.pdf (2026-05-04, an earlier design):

# VBUS A4 CC1 A5 DP1 A6 DN1 A7 SBU1 A8 VBUS A9

## Host 1 USB Port

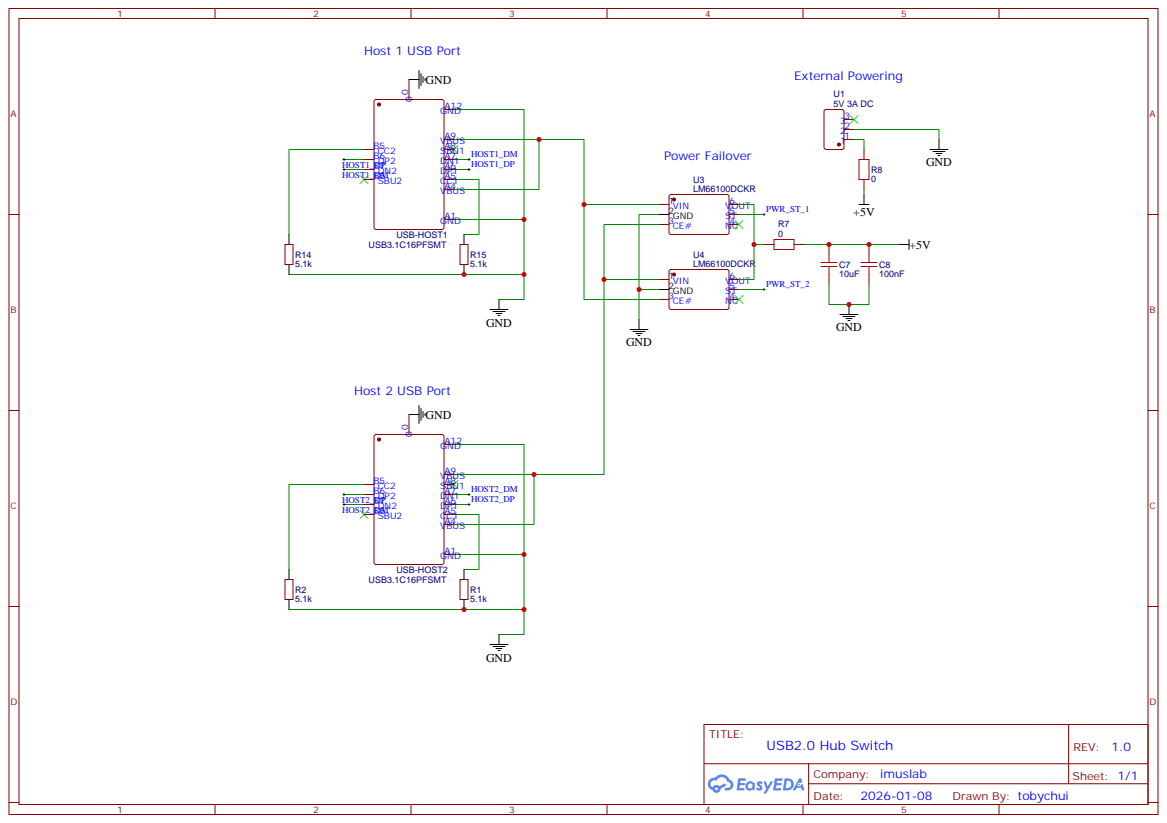
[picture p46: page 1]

## USB Ports Upstream Hub




P3.3/INT1 10 P3.4/PWM2/RXD1_/T0 11 P3.6/UDP 12 P3.7/UDM 13 GND/VSS 14 VCC/VDD 15 V33 16

Host Switch Buttons (Physical)

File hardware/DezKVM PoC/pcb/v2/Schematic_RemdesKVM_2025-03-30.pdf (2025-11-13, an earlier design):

## Upstream USB Port Power Ripple Filter


The port connecting to the KVM control SBC (e.g. Orange Pi)

To USB2UART
To USB HDMI Captuer
To USB Mass Storage

USB to UART
for KVM SBC sending ctrl-signal to KVM

UART to HID
Converting KVM software signal to HID commands

P3.3/INT1 10 P3.4/PWM2/RXD1_/T0 11 P3.6/UDP 12 P3.7/UDM 13 GND/VSS 14 VCC/VDD 15 V33 16

## USB HDMI Capture Card USB HID Downstream Switch


Connect MS2109 USB Capture Device

Use for remote plug & unplug for BIOS / UEFI

DSM_DP/DM from DSM USB Hub

## ATX Power Control


Notes: ATX_PWR_LED and ATX_HDD_LED default to LOW, active HIGH
*This design should be compatible with PiKVM ATX Board Pinsout (Not Tested)*


USB Mass Storage Port
For USB drive or other user required USB hardware

USB Mass Storage Switching Bus
Default to upstream (KVM Host),
set IN to HIGH to switch over to downstream (computer being controlled)

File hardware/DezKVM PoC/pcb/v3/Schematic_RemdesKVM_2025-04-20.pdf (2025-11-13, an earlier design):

## Upstream USB Port Power Ripple Filter


The port connecting to the KVM control SBC (e.g. Orange Pi)

To USB2UART
To USB HDMI Captuer
To USB Mass Storage

USB to UART
for KVM SBC sending ctrl-signal to KVM

UART to HID
Converting KVM software signal to HID commands

P3.3/INT1 10 P3.4/PWM2/RXD1_/T0 11 P3.6/UDP 12 P3.7/UDM 13 GND/VSS 14 VCC/VDD 15 V33 16

## USB HDMI Capture Card USB HID Downstream Switch


Connect MS2109 USB Capture Device

Use for remote plug & unplug for BIOS / UEFI

DSM_DP/DM from DSM USB Hub

Guest USB Port (Mass Storage)
USB device mode for guest system (e.g. PC)

Guest USB Port (HID)


USB Mass Storage Port
For USB drive or other user required USB hardware

USB Mass Storage Switching Bus
Default to upstream (KVM Host),
set IN to HIGH to switch over to downstream (computer being controlled)

## ATX Power Control


Notes: ATX_PWR_LED and ATX_HDD_LED default to LOW, active HIGH
*This design should be compatible with PiKVM ATX Board Pinsout (Not Tested)*

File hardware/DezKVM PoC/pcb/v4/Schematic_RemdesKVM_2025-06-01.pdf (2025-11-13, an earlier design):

## Upstream USB Port Power Ripple Filter


The port connecting to the KVM control SBC (e.g. Orange Pi)

To USB HDMI Captuer

USB to UART
for KVM SBC sending ctrl-signal to KVM

P3.3/INT1 10 P3.4/PWM2/RXD1_/T0 11 P3.6/UDP 12 P3.7/UDM 13 GND/VSS 14 VCC/VDD 15 V33 16

## USB HDMI Capture Card

# DEF 10 SET 11 UD+ 12 UD- 13 GND 14 VCC 15 V33 16


Connect MS2109 USB Capture Device

Guest USB Port (HID)
USB device mode for guest system (e.g. PC)

## ATX Power Control


Notes: ATX_PWR_LED and ATX_HDD_LED default to LOW, active HIGH
*This design should be compatible with PiKVM ATX Board Pinsout (Not Tested)*

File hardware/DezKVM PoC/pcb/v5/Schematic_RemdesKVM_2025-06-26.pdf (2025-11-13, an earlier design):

## Upstream USB Port Power Ripple Filter


The port connecting to the KVM control SBC (e.g. Orange Pi)

To USB HDMI Captuer
To USB Mass Storage SW

USB to UART
for KVM SBC sending ctrl-signal to KVM

DSR# 10 RI# 11 DCD# 12 DTR# 13 RTS# 14 R232 15 VCC 16

## USB HDMI Capture Card

# DEF 10 SET 11 UD+ 12 UD- 13 GND 14 VCC 15 V33 16


Connect MS2109 USB Capture Device

Guest USB Port (Mass Storage)
USB storage device

Guest USB Port (HID)
USB device mode for guest system (e.g. PC)

## ATX Power Control


Notes: ATX_PWR_LED and ATX_HDD_LED default to LOW, active HIGH
*This design should be compatible with PiKVM ATX Board Pinsout (Not Tested)*

P3.3/INT1 10 P3.4/PWM2/RXD1_/T0 11 P3.6/UDP 12 P3.7/UDM 13 GND/VSS 14 VCC/VDD 15 V33 16

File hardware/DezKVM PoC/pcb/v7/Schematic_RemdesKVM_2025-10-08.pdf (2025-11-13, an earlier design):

## Upstream USB Port Power Ripple Filter


The port connecting to the KVM control SBC (e.g. Orange Pi)

To USB HDMI Captuer
To USB Mass Storage SW

USB to UART
for KVM SBC sending ctrl-signal to KVM

HDMI Capture Card Power Ctrl
for remote reset capture card if overheat

DSR# 10 RI# 11 DCD# 12 DTR# 13 RTS# 14 R232 15 VCC 16

## USB HDMI Capture Card

# DEF 10 SET 11 UD+ 12 UD- 13 GND 14 VCC 15 V33 16


Connect MS2109 USB Capture Device

Guest USB Port (Mass Storage)
USB storage device

Guest USB Port (HID)
USB device mode for guest system (e.g. PC)

## ATX Power Control


Notes: ATX_PWR_LED and ATX_HDD_LED default to LOW, active HIGH
*This design should be compatible with PiKVM ATX Board Pinsout (Not Tested)*

P3.3/INT1 10 P3.4/PWM2/RXD1_/T0 11 P3.6/UDP 12 P3.7/UDM 13 GND/VSS 14 VCC/VDD 15 V33 16

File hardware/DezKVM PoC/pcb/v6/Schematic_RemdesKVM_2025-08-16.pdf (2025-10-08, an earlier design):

## Upstream USB Port Power Ripple Filter


The port connecting to the KVM control SBC (e.g. Orange Pi)

To USB HDMI Captuer
To USB Mass Storage SW

USB to UART
for KVM SBC sending ctrl-signal to KVM

DSR# 10 RI# 11 DCD# 12 DTR# 13 RTS# 14 R232 15 VCC 16

## USB HDMI Capture Card

# DEF 10 SET 11 UD+ 12 UD- 13 GND 14 VCC 15 V33 16


Connect MS2109 USB Capture Device

Guest USB Port (Mass Storage)
USB storage device

Guest USB Port (HID)
USB device mode for guest system (e.g. PC)

## ATX Power Control


Notes: ATX_PWR_LED and ATX_HDD_LED default to LOW, active HIGH
*This design should be compatible with PiKVM ATX Board Pinsout (Not Tested)*

P3.3/INT1 10 P3.4/PWM2/RXD1_/T0 11 P3.6/UDP 12 P3.7/UDM 13 GND/VSS 14 VCC/VDD 15 V33 16

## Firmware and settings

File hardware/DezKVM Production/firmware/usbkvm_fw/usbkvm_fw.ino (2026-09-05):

/*
  DezKVM Production Form Factor
  Firmware for PCB design PFFv1

  Author: tobychui

  Upload Settings
  CH552G
  24Mhz (Internal)

  Currently supported commands (hex):
  'm' - Switch USB mass storage to KVM side
  'n' - Switch USB mass storage to remote computer
  'u' - Return the UUID of this device
  'a' - Report status of ATX (if ENABLE_ATX_CTRL is defined)
  'i' - Enable automatic ATX status report (if ENABLE_ATX_CTRL is defined)
  'o' - Disable automatic ATX status report (if ENABLE_ATX_CTRL is defined)
  'p' - Press down the power button (if ENABLE_ATX_CTRL is defined)
  's' - Release the power button (if ENABLE_ATX_CTRL is defined)
  'r' - Press down the reset button (if ENABLE_ATX_CTRL is defined)
  'd' - Release the reset button (if ENABLE_ATX_CTRL is defined)
  '0' - Set LED PROG to LOW
  '1' - Set LED PROG to HIGH
  '2' - Set LED PROG to fast blink
  '3' - Set LED PROG to slow blink
  'f' - Reset echo, return 0xFFFF to host

  The reply follows the format:
  <Length> <Command Identifier> <Payload>
  Note: Length includes the Command Identifier and Payload bytes only, not the Length byte itself.

  Replies command structure:
  0x01 0xFE - Unknown command
  0x01 0xFF - Host read reset echo
  <Length> 0x60 <UUID String> - Reserved for future use
  0x02 0x61 <Status Byte> - ATX status report
  <Length> 0x62 <UUID String> - Device UUID
*/
#include <Serial.h>

/* Build flags */
//#define ENABLE_DEBUG 1     //Enable debug print to Serial, do not use this in IP-KVM setup
#define ENABLE_ATX_CTRL 1  //Enable ATX power control

/* Enums */
#define USB_MS_SIDE_KVM_HOST 0
#define USB_MS_SIDE_REMOTE_PC 1

/* Pins definations */
#define LED_PROG 14
#define ATX_PWR_LED 15
#define ATX_HDD_LED 16
#define ATX_RST_BTN 33
#define ATX_PWR_BTN 34
#define USB_MS_PWR 31  //Active high, set to HIGH to enable USB 5V power and LOW to disable
#define USB_MS_SW 30   //LOW = remote computer, HIGH = KVM

/* Software definations */
#define USB_PWR_SW_PWR_DELAY 100  //ms
#define USB_PWR_SW_DATA_DELAY 10  //ms


/* Runtime variables */
uint8_t atx_status[2] = { 0, 0 };  //PWR LED, HDD LED
uint8_t usb_ms_side = USB_MS_SIDE_REMOTE_PC;
char c;
int led_tmp;
bool led_status = true;  //Default LED PROG state is high, on every command recv it switch state
bool enable_auto_atx_report = false; //Enable automatic ATX status report

/* LED Control Variables */
#define LED_MODE_AUTO 0      //Auto toggle on command receive
#define LED_MODE_OFF 1       //LED forced off
#define LED_MODE_ON 2        //LED forced on
#define LED_MODE_FAST 3      //Fast blink (200ms)
#define LED_MODE_SLOW 4      //Slow blink (1000ms)
uint8_t led_mode = LED_MODE_SLOW; //Default LED mode is slow blink
unsigned long led_last_toggle = 0;
bool led_blink_state = false;

/* Function Prototypes */
void report_status();
void update_atx_led_status();
void switch_usbms_to_kvm();
void switch_usbms_to_remote();
void print_device_uuid();
void get_usb_mass_storage_side();

//execute_cmd match and execute host to remote commands
void execute_cmd(char c) {
  switch (c) {
    case 'm':
      //Switch USB mass storage to KVM side
      switch_usbms_to_kvm();
      break;
    case 'n':
      //Switch USB mass storage to remote computer
      switch_usbms_to_remote();
      break;
    case 'u':
      //Return the UUID of this device
      print_device_uuid();
      break;
    case 'y':
      //Get USB mass storage side
      get_usb_mass_storage_side();
      break;
#ifdef ENABLE_ATX_CTRL
    case 'a':
      //Report status of ATX
      report_status();
      break;
    case 'i':
      //Enable automatic ATX status report
      enable_auto_atx_report = true;
      break;
    case 'o':
      //Disable automatic ATX status report
      enable_auto_atx_report = false;
      break;
    case 'p':
      //Press down the power button
      digitalWrite(ATX_PWR_BTN, HIGH);
      break;
    case 's':
      //Release the power button
      digitalWrite(ATX_PWR_BTN, LOW);
      break;
    case 'r':
      //Press down the reset button
      digitalWrite(ATX_RST_BTN, HIGH);
      break;
    case 'd':
      //Release the reset button
      digitalWrite(ATX_RST_BTN, LOW);
      break;
#endif /* ~ENABLE_ATX_CTRL */
    /* LED Control Signals */
    case '0':
      //Set LED PROG to LOW
      led_mode = LED_MODE_OFF;
      digitalWrite(LED_PROG, LOW);
      break;
    case '1':
      //Set LED PROG to HIGH
      led_mode = LED_MODE_ON;
      digitalWrite(LED_PROG, HIGH);
      break;
    case '2':
      //Set LED PROG to fast blink
      led_mode = LED_MODE_FAST;
      led_last_toggle = millis();
      led_blink_state = false;
      break;
    case '3':
      //Set LED PROG to slow blink
      led_mode = LED_MODE_SLOW;
      led_last_toggle = millis();
      led_blink_state = false;
      break;
    /* ~LED Control Signals */
    case 'f':
      //Reset echo, return 0xFFFF to host
      USBSerial_print(0x01); //Length
      USBSerial_print(0xFF); //Ack: Reset Echo
      break;
    default:
      //Unknown command
      USBSerial_println(0x01); //Length
      USBSerial_println(0xFE); // Ack: Error: Unknown Command
      break;
  }

}


void setup() {
  pinMode(ATX_PWR_LED, INPUT);
  pinMode(ATX_HDD_LED, INPUT);
  pinMode(ATX_RST_BTN, OUTPUT);
  pinMode(ATX_PWR_BTN, OUTPUT);
  pinMode(USB_MS_PWR, OUTPUT);
  pinMode(USB_MS_SW, OUTPUT);
  pinMode(LED_PROG, OUTPUT);

  digitalWrite(LED_PROG, HIGH);
  digitalWrite(ATX_RST_BTN, LOW);
  digitalWrite(ATX_PWR_BTN, LOW);
  digitalWrite(USB_MS_PWR, LOW);
  digitalWrite(USB_MS_SW, LOW);

  //Blink 10 times for initiations
  for (int i = 0; i < 10; i++) {
    digitalWrite(LED_PROG, HIGH);
    delay(100);
    digitalWrite(LED_PROG, LOW);
    delay(100);
  }
  digitalWrite(LED_PROG, HIGH);
  delay(1000);
#ifdef ENABLE_DEBUG
  USBSerial_println("[WARNING] The current firmware has debug mode turned on. Do not use in production or IP-KVM setup!");
#endif /* ENABLE_DEBUG */
  //Switch the USB thumbnail to host
  switch_usbms_to_kvm();
  delay(1000);
}

void loop() {
  if (USBSerial_available()) {
    c = USBSerial_read();
#ifdef ENABLE_DEBUG
    USBSerial_print("[DEBUG] Serial Recv: ");
    USBSerial_println(c);
#endif /* ENABLE_DEBUG */
    execute_cmd(c);

    //Only toggle LED on command receive if in auto mode
    if (led_mode == LED_MODE_AUTO) {
      led_status = !led_status;
      digitalWrite(LED_PROG, led_status ? HIGH : LOW);
    }
  }

  //Handle LED blinking modes
  if (led_mode == LED_MODE_FAST || led_mode == LED_MODE_SLOW) {
    unsigned long current_time = millis();
    unsigned long blink_interval = (led_mode == LED_MODE_FAST) ? 200 : 1000;

    if (current_time - led_last_toggle >= blink_interval) {
      led_blink_state = !led_blink_state;
      digitalWrite(LED_PROG, led_blink_state ? HIGH : LOW);
      led_last_toggle = current_time;
    }
  }

#ifdef ENABLE_ATX_CTRL
  update_atx_led_status();
  if (enable_auto_atx_report) {
    report_status();
  }
#endif /* ENABLE_ATX_CTRL */

  delay(100);
}

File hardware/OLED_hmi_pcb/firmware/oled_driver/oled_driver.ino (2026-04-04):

/*
   DezKVM OLED Driver Board
   Firmware

   Author: tobychui

   Upload Settings
   CH552G
   24Mhz (Internal)

*/

// Comment the line below to disable touch buttons
//#define ENABLE_TOUCH_BUTTONS

#include <Serial.h>
#include <SoftI2C.h>
#include <TouchKey.h>
#include "oled_driver.h"

/* Runtime command variables */
uint8_t cmd_bytes[CMD_MAX_LENGTH];
uint8_t next_cmd_def = CMD_DEF_LENGTH;
uint8_t cmd_len_remain = 0;
int cmd_write_pos = 0;

/* Font memory buffer */
uint8_t font_buf[FONT_CHAR_SIZE];

/* Emergency reset tracking */
uint8_t enable_reset_bytes = 1;
uint8_t reset_byte_count = 0;

/* Display content buffer, see oled_i2c.ino */
extern uint8_t display_contents[OLED_MAX_CHAR_COUNT];

//process_cmd process cmd_bytes when the whole command is recv
void process_cmd() {
  uint8_t cmd_length = cmd_bytes[0];
  uint8_t cmd_type = cmd_bytes[1];

  if (cmd_type == CMD_CLEAR_SCREEN) {
    // 0x01: Clear screen
    // [0x01] [0x01]
    OLED_clear_screen();
    USBSerial_write(0xF0);
    USBSerial_flush();
  } else if (cmd_type == CMD_SET_SCREEN_CONTENT) {
    // 0x03: Set screen content and render
    // [len] [0x03] [OLED_MAX_CHAR_COUNT ASCII bytes]
    int padding = 0;
    int payload_length = cmd_length - 1; //remove the type byte
    if (payload_length < OLED_MAX_CHAR_COUNT) {
      padding = OLED_MAX_CHAR_COUNT - payload_length;
    }
    for (uint8_t i = 0; i < OLED_MAX_CHAR_COUNT; i++) {
      display_contents[i] = cmd_bytes[2 + i];
    }
    for (uint8_t i = 0; i < padding; i++) {
      display_contents[payload_length + i] = 0x20;
    }
    OLED_render_screen();
    USBSerial_write(0xF0);
    USBSerial_flush();
  } else if (cmd_type == CMD_WRITE_RAW_FONT_BUF) {
    // 0x04: Take the input bytes and fill the font buffer directly
    // font buffer size are either 8x8 or 16x16 depeneds on oled_dirver.h definations
    // [len] [0x04] [render position] [Raw bytes to write to font_buffer]

    // Check if cmd_bytes payload matches the font char size
    // cmd_length = type(1) + position(1) + font_data, so font_data = cmd_length - 2
    if (cmd_length - 2 != FONT_CHAR_SIZE) {
      //corrupted data
      USBSerial_write(0xF1);
      USBSerial_flush();
      return;
    }

    // Check if render position is within range
    uint8_t render_position = cmd_bytes[2];
    if (render_position >= OLED_MAX_CHAR_COUNT) {
      //out of bound
      USBSerial_write(0xF1);
      USBSerial_flush();
      return;
    }

    // Copy data from cmd_bytes to font_buf
    // font data starts at cmd_bytes[3], ends at cmd_bytes[2 + FONT_CHAR_SIZE]
    for (uint8_t i = 3; i < FONT_CHAR_SIZE + 3; i++) {
      font_buf[i - 3] = cmd_bytes[i];
    }
    //Append it to display
    OLED_render_buf_to_screen(render_position);
    USBSerial_write(0xF0);
    USBSerial_flush();
  } else if (cmd_type == CMD_CLEAR_FONT_BUF) {
    // 0x05: Clear font buffer
    for (uint8_t i = 0; i < FONT_CHAR_SIZE; i++) {
      font_buf[i] = 0x20; //Space, no pixels
    }
    USBSerial_write(0xF0);
    USBSerial_flush();
  } else if (cmd_type == CMD_WRITE_CHAR_AT_IDX) {
    // 0x06: Write / append font at given index
    // [len] [0x06] [render position] [ascii_code]
    uint8_t font_idx = cmd_bytes[2];
    if (font_idx >= OLED_MAX_CHAR_COUNT) {
      //out of bound
      USBSerial_write(0xF1);
      USBSerial_flush();
      return;
    }

    // Load and render to screen
    uint8_t ascii_code = cmd_bytes[3];
    EEPROM_LoadFontData(ascii_code);
    OLED_render_buf_to_screen(font_idx);
    USBSerial_write(0xF0);
    USBSerial_flush();
  } else if (cmd_type == CMD_WRITE_FONT_DATA) {
    // 0xC3: Write font data to EEPROM
    // [len] [0xC3] [ascii_code] [FONT_CHAR_SIZE bytes font data]
    uint8_t ascii_code = cmd_bytes[2];
    // Move the font data from cmd to font_buf
    // cmd_bytes[3..cmd_length] = 32 bytes of font data (indices 3 to 34 inclusive)
    for (int i = 3; i <= cmd_length; i++) {
      font_buf[i - 3] = cmd_bytes[i];
    }
    //Write data to EEPROM
    EEPROM_WriteFontData(ascii_code);
    // Success, return 0xF0
    USBSerial_write(0xF0);
    USBSerial_flush();

  } else if (cmd_type == CMD_LOAD_FONT_DATA) {
    // 0xC4: Read font from EEPROM, print to serial
    // [0x03] [0xC4] [ascii_code]
    uint8_t ascii_code = cmd_bytes[2];
    EEPROM_LoadFontData(ascii_code);
    for (uint8_t i = 0; i < FONT_CHAR_SIZE; i++) {
      USBSerial_write(font_buf[i]);
    }
    USBSerial_flush();

  } else if (cmd_type == CMD_LOAD_FONT_TO_OLED) {
    // 0xC5: Load font from EEPROM, display at first position
    // [0x03] [0xC5] [ascii_code]
    uint8_t ascii_code = cmd_bytes[2];
    OLED_clear_screen();
    OLED_set_char(0, ascii_code);
    OLED_render_screen();
    USBSerial_write(0xF0);
    USBSerial_flush();

  } else if (cmd_type == CMD_WRITE_EEPROM_RAW) {
    // 0xC6: Write raw data to EEPROM at 16-bit address
    // [len] [0xC6] [addr_h] [addr_l] [data... up to 32 bytes]
    uint16_t addr = ((uint16_t)cmd_bytes[2] << 8) | cmd_bytes[3];
    uint8_t data_len = cmd_bytes[0] - 3; // length - type(1) - addr(2)
    if (data_len > 32) {
      USBSerial_write(0xF1);
      USBSerial_flush();
      return;
    }
    EEPROM_WriteRaw(addr, &cmd_bytes[4], data_len);
    USBSerial_write(0xF0);
    USBSerial_flush();

  } else if (cmd_type == CMD_READ_EEPROM_RAW) {
    // 0xC7: Read raw data from EEPROM at 16-bit address
    // [0x04] [0xC7] [addr_h] [addr_l] [count]
    uint16_t addr = ((uint16_t)cmd_bytes[2] << 8) | cmd_bytes[3];
    uint8_t read_len = cmd_bytes[4];
    if (read_len > 32) read_len = 32;
    uint8_t read_buf[32];
    EEPROM_ReadRaw(addr, read_buf, read_len);
    for (uint8_t i = 0; i < read_len; i++) {
      USBSerial_write(read_buf[i]);
    }
    USBSerial_flush();
  }
}
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

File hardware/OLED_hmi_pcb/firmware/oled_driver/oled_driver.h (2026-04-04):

/* Hardware definations */
#define LED_PIN 14
#define TOUCHPAD_A 15
#define TOUCHPAD_B 16
#define I2C_SDA 31
#define I2C_SCL 30

/*
    HMI command types (Length-Type-Value format)

    The length do not contain length bytes, for example:
    0x02 0xC4 0x20 (CMD_LOAD_FONT_DATA of 0x20)

    On command success, return 0xF0
    On command failed, return 0xF1
*/

/* CMD byte type enum */
#define CMD_DEF_LENGTH 0x00
#define CMD_DEF_TYPE 0x01
#define CMD_DEF_VALUE 0x02

/* CMD_MAX_LENGTH: large enough for the biggest command payload + headroom */
#define CMD_MAX_LENGTH 130

// OLED drawing commands
#define CMD_CLEAR_SCREEN 0x01 //Clear the OLED screen
#define CMD_LIGHT_SCREEN 0x02 //Light up the OLED screen with all pixels
#define CMD_SET_SCREEN_CONTENT 0x03 //Set the screen content to render, follow by OLED_MAX_CHAR_COUNT ASCII characters
#define CMD_WRITE_RAW_FONT_BUF 0x04 //Write bytes to raw font buffer, font buffer size depends on terminal mode font size
#define CMD_CLEAR_FONT_BUF 0x05 //Clear the font buffer
#define CMD_WRITE_CHAR_AT_IDX 0x06 //Write ascii char at given grid location (overwrite)

//To be added

// Touch interrupt events
#define TOUCHKEY_LONGPRESS_SECOND_THRESHOLD 2 //Seconds to trigger long press event
#define CMD_EVENT_TOUCH_A_DOWN 0xB0 // Touch button A is pressed
#define CMD_EVENT_TOUCH_A_UP 0xB1 // Touch button A is released
#define CMD_EVENT_TOUCH_B_DOWN 0xB2 // Touch button B is pressed
#define CMD_EVENT_TOUCH_B_UP 0xB3 // Touch button B is released
#define CMD_EVENT_TOUCH_A_LONG_PRESS 0xB4 // Touch button A is long pressed
#define CMD_EVENT_TOUCH_B_LONG_PRESS 0xB5 // Touch button B is long pressed

// EMMC flasing and debug commands
#define CMD_WRITE_FONT_DATA 0xC3 //Write font data to EEPROM, <len> 0xC3 <ASCII code (1 byte)> <font_data (FONT_CHAR_SIZE bytes)>
#define CMD_LOAD_FONT_DATA 0xC4 //Load font data to serial for debug 0x02 0xC4 <ASCII code (1 byte)>
#define CMD_LOAD_FONT_TO_OLED 0xC5 //Load font data to OLED screen first position, 0x02 0xC5 <ASCII code (1 byte)>
#define CMD_WRITE_EEPROM_RAW 0xC6 //Write raw data to EEPROM, [len] 0xC6 [addr_h] [addr_l] [data... up to 32 bytes]
#define CMD_READ_EEPROM_RAW  0xC7 //Read raw data from EEPROM, [0x04] 0xC7 [addr_h] [addr_l] [count], returns count raw bytes
#define CMD_RESET 0xCF //Reset and celar the cmd_bytes

/* I2C Address */
#define OLED_ADDR 0x3C
#define EEPROM_ADDR 0x50 //24C32

/* OLED */
// Commands for SSD1306
#define SSD1306_DISPLAYOFF 0xAE
#define SSD1306_SETDISPLAYCLOCKDIV 0xD5
#define SSD1306_SETMULTIPLEX 0xA8
#define SSD1306_SETDISPLAYOFFSET 0xD3
#define SSD1306_SETSTARTLINE 0x40
#define SSD1306_CHARGEPUMP 0x8D
#define SSD1306_MEMORYMODE 0x20
#define SSD1306_SEGREMAP 0xA1
#define SSD1306_COMSCANDEC 0xC8
#define SSD1306_SETCOMPINS 0xDA
#define SSD1306_SETCONTRAST 0x81
#define SSD1306_SETPRECHARGE 0xD9
#define SSD1306_SETVCOMDETECT 0xDB
#define SSD1306_DISPLAYALLON_RESUME 0xA4
#define SSD1306_NORMALDISPLAY 0xA6
#define SSD1306_DISPLAYON 0xAF

// Hardware definations
#define FONT_GRID_SIZE 8
#define OLED_COLS (128 / FONT_GRID_SIZE)
#define OLED_ROWS (64 / FONT_GRID_SIZE)
#define OLED_MAX_CHAR_COUNT (OLED_COLS * OLED_ROWS)
#define OLED_PAGES_PER_CHAR (FONT_GRID_SIZE / 8)

// Function prototypes
void OLED_WriteCmd(uint8_t command);
void OLED_WriteData(uint8_t data);
void initializeOLED();
void clearScreen();
void lightScreen();
void OLED_clear_screen(void);
void OLED_set_char(uint8_t idx, uint8_t ascii);
void OLED_render_screen(void);
void OLED_render_buf_to_screen(uint8_t idx);
void OLED_ender_boot_animation_loop();

/* EEPROM Font Mapping
   Each character: FONT_GRID_SIZE rows x FONT_BYTES_PER_ROW bytes = FONT_CHAR_SIZE bytes
   Address = (ascii_code - 0x20) * FONT_CHAR_SIZE
*/

/* Boot Animation Frames (128x64 px, 1 bit/pixel = 1024 bytes per frame) */
#define BOOT_ANIMATION_FRAME_SIZE  1024
#define BOOT_ANIMATION_START_ADDR  0x0300
#define BOOT_ANIMATION_FRAME_COUNT 3
#define BOOT_ANIMATION_FRAME_DELAY 50
#define FONT_BYTES_PER_ROW  ((FONT_GRID_SIZE + 7) / 8)
#define FONT_CHAR_SIZE      (FONT_GRID_SIZE * FONT_BYTES_PER_ROW)
#define FONT_ASCII_OFFSET   0x20

/* EEPROM Function Prototypes */
void EEPROM_WriteFontData(uint8_t ascii_code);
void EEPROM_LoadFontData(uint8_t ascii_code);
void EEPROM_WriteRaw(uint16_t addr, uint8_t* data, uint8_t len);
void EEPROM_ReadRaw(uint16_t addr, uint8_t* buf, uint8_t len);

/* Touchkey Function Prototypes */
void touch_key_init(void);
void process_touch_key_events(void);

/* UUID services, for DezKVM USB device discovery protocol */
void print_device_uuid(void);

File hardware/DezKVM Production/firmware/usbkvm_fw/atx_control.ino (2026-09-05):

/*
  atx_control.ino
  author: tobychui

  This file include functions that handles
  ATX power control and switching.

  Note: Not all versions of RemdesKVM have
  ATX hardware populated

  Reply Command Structure
  0x02 0x61 <Status Byte>
*/


void update_atx_led_status() {
  led_tmp = digitalRead(ATX_PWR_LED);
  atx_status[0] = led_tmp;
  led_tmp = digitalRead(ATX_HDD_LED);
  atx_status[1] = led_tmp;
}

void report_status() {
  //Report status of ATX and USB mass storage switch in 1 byte
  //Bit 0: PWR LED status
  //Bit 1: HDD LED status
  //Bit 2: USB Mass Storage mounted side
  //Bit 3 - 7: Reserved
  uint8_t status = 0x00;
  status |= (atx_status[0] & 0x01);
  status |= (atx_status[1] & 0x01) << 1;
  status |= (usb_ms_side & 0x01) << 2;
#if ENABLE_DEBUG == 1
  USBSerial_print("[DEBUG] ATX State");
  USBSerial_print("PWR=");
  USBSerial_print(atx_status[0]);
  USBSerial_print(" HDD=");
  USBSerial_print(atx_status[1]);
  USBSerial_print(" USB_MS=");
  USBSerial_println(usb_ms_side);
#endif
  USBSerial_write(0x02); //Length byte (1 byte command + 1 byte status)
  USBSerial_write(0x61); //Command identifier
  USBSerial_write(status); //Status byte
}

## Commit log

2025-09-21 Add video capture configuration guidelines to README
    Added a section detailing supported resolutions, frame rates, and estimated bandwidth requirements for the MS2109 HDMI capture card. This helps users select appropriate settings based on their networ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
2025-10-08 Added v6 pcb
    [BOM_RemdesKVM_2025-08-16.csv, PickAndPlace_RemdesKVM_v6_2025-08-16.csv]
2025-11-13 Added v7 PCB
2025-11-13 Restructure project layout and migrate source files
    [BOM_RemdesKVM_2025-08-16.csv, PickAndPlace_RemdesKVM_v6_2025-08-16.csv, capture_holder_bottom.stp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]
2026-02-22 Add Install Dependencies section to README
    Add a new "Install Dependencies" subsection to the README explaining kernel and distro recommendations and listing packages required to build and run DezKVM. Provides apt commands to install build-essential, libv4l-dev, v4l-utils for missing v4l2 types/user-space properties, and alsa-utils to address audio capture/device property issues; suggests running both installs before `go build`.
2026-02-26 Add DB module; refactor auth & add kvm aux
    Introduce a new db package wrapping BoltDB for safe, bucketed KV ops and provide a shared DB instance for the application. Refactor AuthManager to accept and use the shared DB (moved DB logic out of auth), extract auth HTTP handlers to auth_handlers.go, and centralize API registration into dedicated handler functions. Add system DB initialization and integrate it into ipkvm initialization, start an SSH proxy manager, and register terminal APIs. Add a kvmaux module to control the auxiliary MCU over serial (USB mass storage switching, power/reset, LED/status, UUID queries). Add screenshot handler in dezkvm handlers and minor fixes: CH9329 product stri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
2026-02-28 Add ATX control board PCB
    [BOM_RemdesKVM_2026-02-28.csv]
2026-03-15 Add new ATX board design
    [BOM_RemdesKVM_2026-02-28.csv, atx-adapter_cable-press.ipt, atx-adapter_cable-press.stl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]
2026-03-15 Removed extra files
    [atx-adapter_mount.0011.ipt, pcie-bracket.0021.ipt, test_fit.0002.iam]
2026-04-04 Reorganize hardware into 'DezKVM PFF'
    Move and rename hardware model, case and PCB files into a new 'hardware/DezKVM PFF' subtree (files preserved, 100% similarity). Remove the embedded README image reference and delete hardware/img/READ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
    [BOM_RemdesKVM_2025-08-16.csv, PickAndPlace_RemdesKVM_v6_2025-08-16.csv, capture_holder_bottom.stp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]
2026-04-04 Restructure repo and OLED driver code
    [BOM_RemdesKVM_2025-08-16.csv, BOM_RemdesKVM_2025-11-29.csv, PickAndPlace_RemdesKVM_v6_2025-08-16.csv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]
2026-04-19 Add HID prefs, mouse jiggler, serial backend
    Introduce preferences, mouse jiggler, and improved serial handling with related APIs and persistence.
    - Add UsbKvmPreferences with defaults and Save/Load persistence per-instance (config folder support).
    - Implement mouse jiggler (auto moves when idle) with HTTP endpoints to get/set state and preferences; apply prefs on start.
    - Add low-level serial package for reliable CDC ACM handling (termios, timeouts, flush) and switch AuxMCU to use it to avoid hang/close issues.
    - Add status LED control helpers and integrate LED state changes during HID websocket sessions and device startup.
    - Improve HID websocket: bounded command queue, ACK replies for co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
2026-05-04 Add open source USB KVM switch
    Added software control USB KVM switch hardwares
    [BOM_USB-2.0-KVM-Switch-Hub_2026-04-15.csv, PickAndPlace_PCB_USB-2.0-KVM-Switch-Hub_2026-04-15.csv, PickAndPlace_PCB_USB-2.0-KVM-Switch-Hub_2_2026-04-15.csv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]
2026-09-05 Move USB-KVM firmware from pcb/ into its own firmware/ directory
    Separates the ATmega firmware sources from the PCB design folder so
    pcb/ only holds board files. Drops the per-editor .vscode/ config at
    the old location and ignores it at the new one instead.
2026-09-05 Add FFv1 fabrication outputs for the DezKVM PCB
    BOM, Gerber files, board layout JSON, and schematic for the first
    production fab run.
    [BOM_RemdesKVM_2025-12-28.csv]
2026-09-05 Add file/media thumbnail rendering module
    New mod/thumbnails package generating JPEG previews for audio (ID3
    art), images, RAW, PSD, SVG, video (via ffmpeg/exec), and G-code
    files, cached under ./thumb/{device}/{path}.jpg. Ported from the
    arozos project per its header comments. Not yet wired into the
    daemon.
2026-09-05 Add USB mass-storage, file-manager, and ISO/disk-image library feature
    Backend: partition/format/mount utilities and the file-manager
    (mod/dezkvm/storage/*), the host-side ISO library (mod/isostore), the
    extracted per-device lifecycle and mass-storage-mount logic
    (instance.go, replacing the stale duplicate usbkvm.go which redefined
    the same methods and no longer compiled), USB-hub storage-device
    discovery (kvmscan.go), the EnableMassStorage/MassStoragePTUUID config
    fields (typedef.go), removal of the now-superseded per-MCU
    HandleSwitchUSBToKVM/Remote HTTP handlers plus an LED-blink-on-close
    fix (kvmaux), and the new storage/ISO HTTP handlers plus the ATX
    handler methods used by a later commi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
2026-09-05 Add WebRTC H.264 video streaming
    mod/videnc abstracts hardware/software H.264 encoding (Intel VA-API,
    V4L2M2M for RPi/OrangePi, software fallback). mod/webrtcstream is a
    pion-based WHEP-style SDP offer/answer bridge that feeds MJPEG frames
    into RTP. mod/dezkvm/webrtc.go and webrtc_handlers.go add the
    per-instance session handlers.
    mod/usbcapture is reworked to support a second consumer of the same
    frame stream: frame_source.go is new, and typedef.go/usbcapture.go/
    video_device.go replace the old single accessCount+videoTakeoverChan
    fields with a mutex-guarded videoConsumer, plus optional software
    JPEG re-compression. video_device.go also fixes an unrelated bug in
    GetV4L2FormatInfo where FPS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
2026-09-05 Add ATX power-control feature (front-panel power/reset via aux MCU)
    Thin HTTP wrappers delegating to the HandleATXState/HandleATXTrigger
    methods added on mod/dezkvm's handlers.go, plus the Power tool panel.
2026-09-05 Wire storage, ISO, thumbnail, WebRTC, and ATX routes into the daemon
    api.go reorganizes and extends register_ipkvm_apis with the new
    endpoint groups (HID/mouse-jiggler, streaming, WebRTC, mass-storage,
    ATX, storage/file-manager, ISO-write, ISO library, settings). ipkvm.go
    initializes the new isoManager/thumbRenderer singletons. main.go adds
    a debug CLI subcommand. tools.go adds precheck warnings for
    disk-format tools (lsblk, parted, mkfs.*) and ffmpeg (WebRTC), and
    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
2026-09-05 Add dez-ui component/window framework, toolbox, icon set, and Inter font
    New lightweight jQuery-plugin-compatible UI kit (dez-ui.js/css)
    replacing Fomantic-UI's JS with $.toast, .modal(), .dropdown(), etc.,
    plus the DezWindow draggable floating-window factory. Adds the
    floating Tools launcher (toolbox.js/css), the new SVG icon set, and
    the bundled Inter variable font.
    Migrates login.html, no_session.html, terminal.html, and
    forgot-password.html to the new stylesheet/script pair, dropping the
    full Fomantic-UI CSS/JS bundle for just its icon CSS. terminal.html
    also gets a small unrelated iframe-sizing simplification (inset:0
    instead of four offsets), an auto-connect fix (hide
    #connectionSetti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
2026-09-05 Add refreshed logo/branding assets
    Design-source and exported font-logo files. Not yet referenced
    anywhere in the app (the existing font_logo.svg/logo.svg are
    unchanged in content) — staged for a future swap-in.
2026-09-05 Redesign the app shell: top bar, device selector, ATX quick actions
    Full rewrite of main.js (device list, terminal-session management now
    backed by the new tools/terminal-manager.html, side panel, ATX quick
    buttons, theme toggle, ISO-library window) and index.html/main.css to
    the new dez-ui shell chrome. on-screen-keyboard.html gets a trivial
    title-text change ("Virtual Keyboard" -> "On-screen Keyboard").
2026-09-05 Wire WebRTC mode switching, mass-storage, and new settings tabs into viewport
    kvmevt.js: setStreamingSource now asks the backend which streaming
    mode to use and calls into webrtc-stream.js when appropriate. Also
    fixes a paste-textarea bug where pasted text was read from .innerHTML
    instead of .value (corrupting pasted text), an audio-autoplay/resume
    fix, and a key-stack empty-clear toast fix.
    viewport.js adds notifyStorageSideChanged() and a postMessage bridge
    so the File Transfer tool learns when the mass-storage side flips, an
    MJPEG-only guard on the stream-reload cache-buster (WebRTC restarts
    itself instead), and legacy openFileManagerPopup/closeFileManagerPopup
    shims onto the toolbox.
    s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
